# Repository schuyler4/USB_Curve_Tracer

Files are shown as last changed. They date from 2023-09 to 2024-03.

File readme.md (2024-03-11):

<h2> USB Curve Tracer </h2>
This is my attempt at making a curve tracer.  
Instead of implementing a display, data is piped to an external computer where it is plotted using Python. It is also controlled using a command line interface on the external computer. 

Device Picture

<h3> Revision 3 Specs </h3>
<ul>
<li>12V External Power Supply</li>
<li>Maximum Positive Sweep Voltage: 4V</li>
<li>Minimum Negative Sweep Voltage: -3.9V</li>
<li>Full Sweep Time: 15.4s</li>
</ul>

<h3> Limitations </h3>
<ul>
<li>The curve tracer does not use sinusoidal waveforms for measurement; measuring reactive components 
(Capacitors and Inductors) probably will not work. </li>
<li>The curve tracer cannot be driven, so it cannot measure voltage sources.</li>
<li>The curve tracer does not include Kelvin connection functionality, so test lead resistance and 
contact resistance will be included in the measurement. </li>
<li> The curve tracer does not include any programmable gain stages. For this reason, you only get full
current/voltage measurement when using the full current/voltage range.</li>
</ul> 

<h3> Examples </h3>
<p>Below is an example 1N4148 diode sweep and a 2N3904 BJT sweep. Short of curve tracing with a different system and doing a comparison, there is not really a good way to verify if these are correct. However, the general shape of the curves does look right. There is clearly some offset error for the red trace of the 2N3904 sweep. </p>

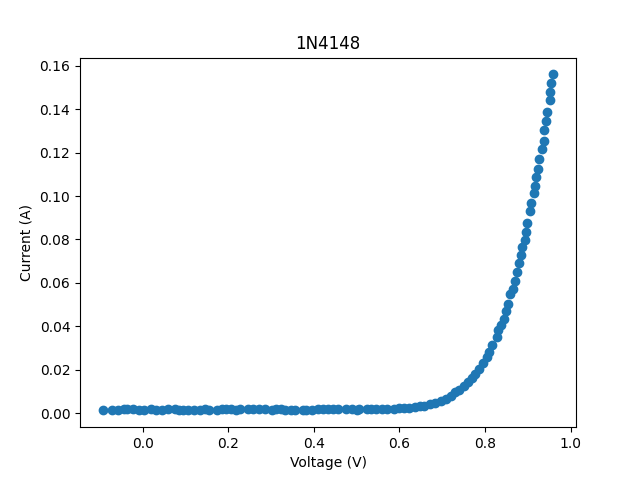
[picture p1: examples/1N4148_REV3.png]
1N4148 Diode

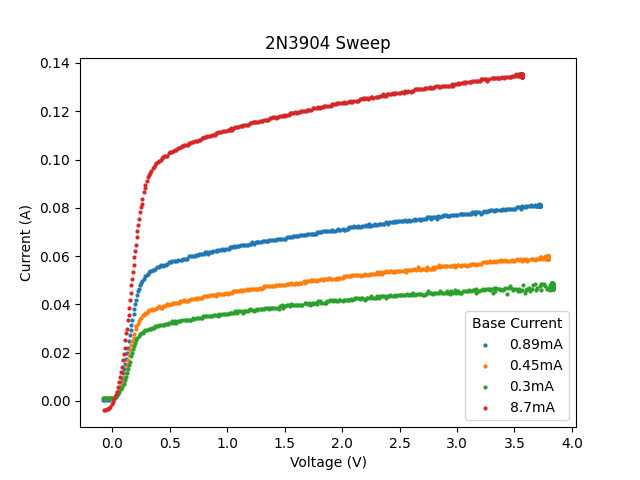
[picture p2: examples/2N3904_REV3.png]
2N3904 BJT


<h3> Schematic </h3>

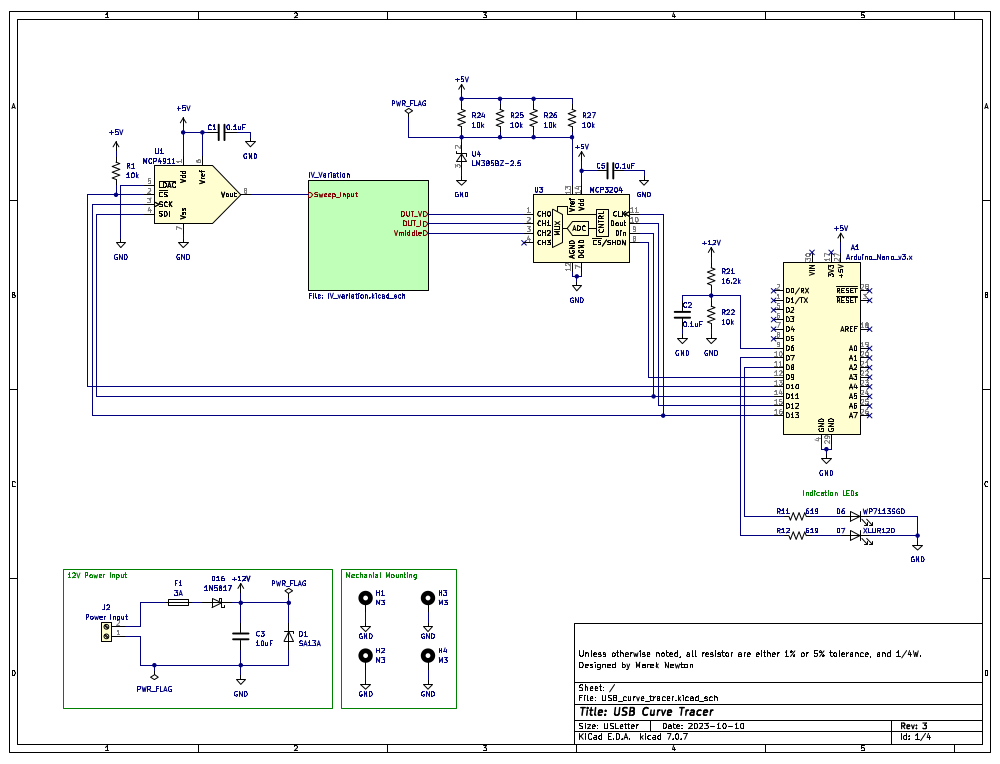
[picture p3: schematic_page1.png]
Schematic Page 1

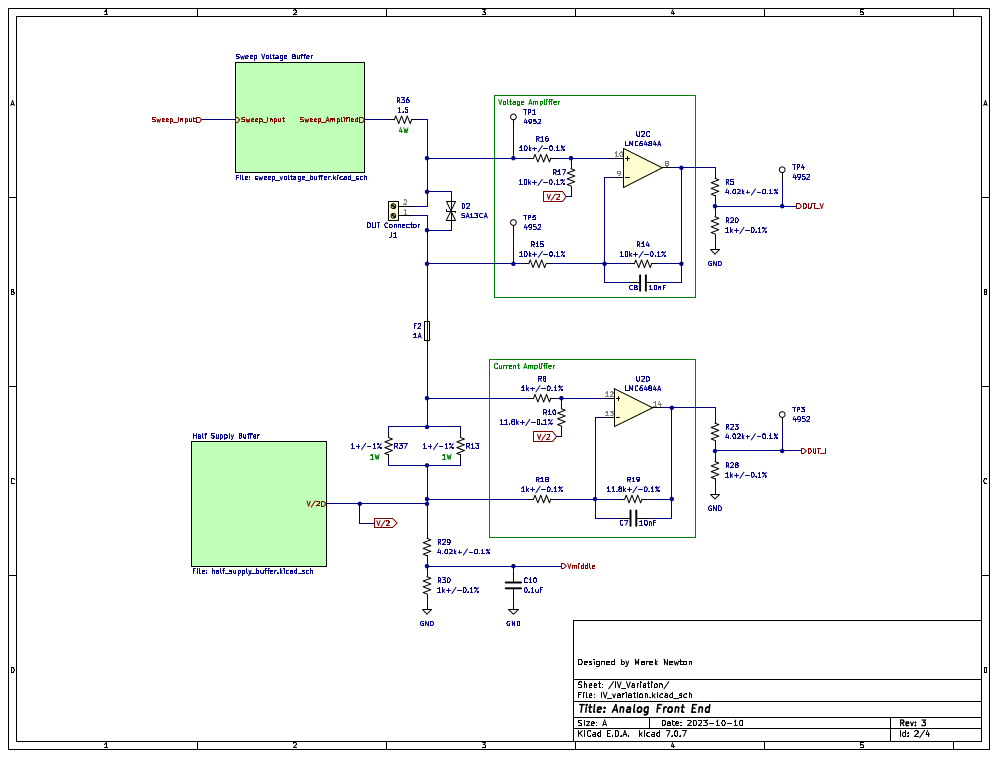
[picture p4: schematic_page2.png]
Schematic Page 2

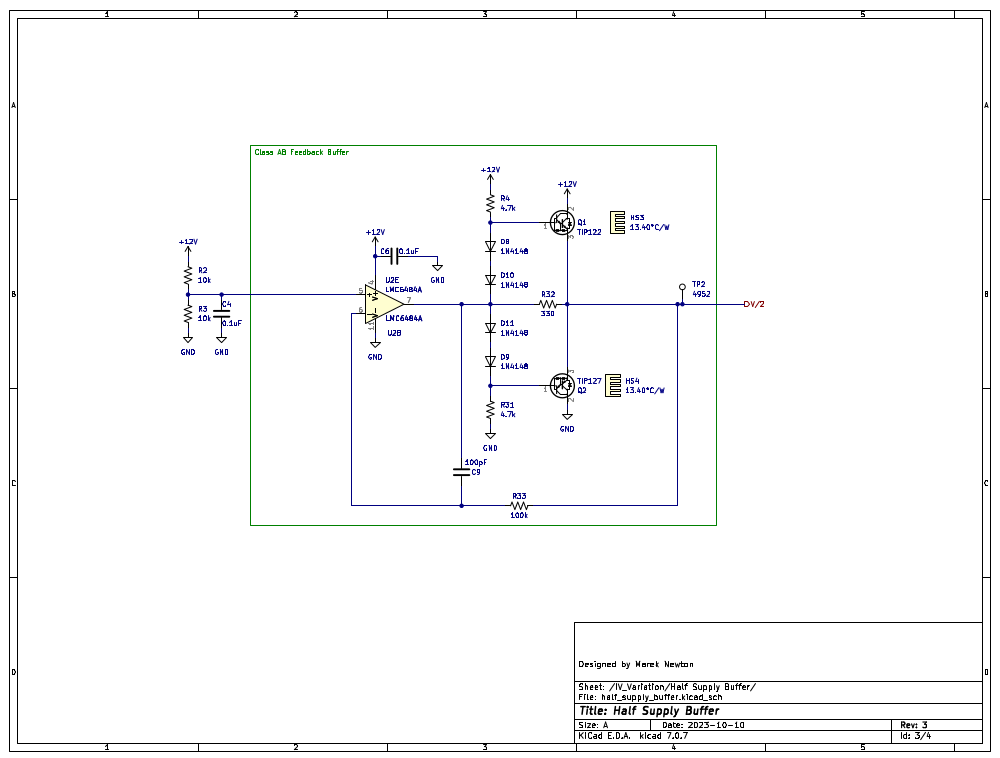
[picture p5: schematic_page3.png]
Schematic Page 3

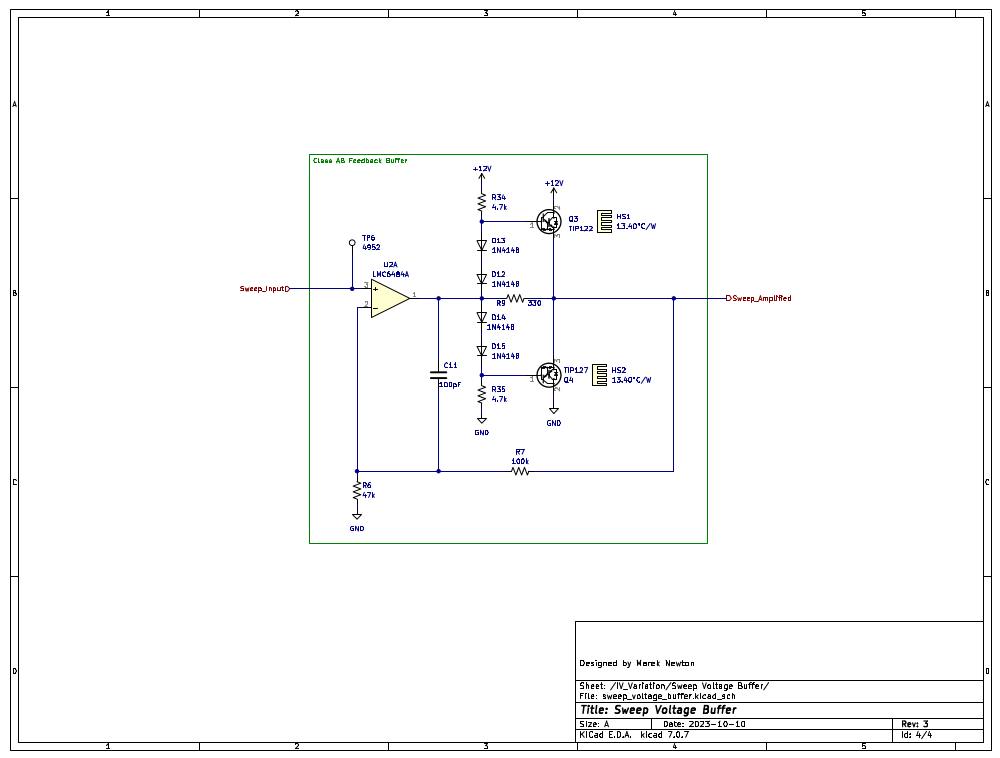
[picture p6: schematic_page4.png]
Schematic Page 4


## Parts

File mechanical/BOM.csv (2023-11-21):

Item | Qty | Value | Distributor | Distributor Part # | Part # | Unit Price | Price
1 | 1 | Enclosure | DIGIKEY | HM616-ND | 1411QU | 16.34 | 16.34
2 | 2 | Red Banana Jack | DIGIKEY | J151-ND | 108-0902-001 | 1.17 | 2.34
3 | 3 | Black Banana Jack | DIGIKEY | J152-ND | 108-0903-001 | 1.26 | 3.78
4 | 4 | Feet | DIGIKEY | SJ-5023-BLACK-ND | SJ-5023-BLACK | 0.29 | 1.16
total: |  |  |  |  |  |  | 23.62
"Assorted M3 screws | M3 nuts | M3 washers | wire | and heatshink are also needed. Standoffs can be 3D printed with the given files.
"

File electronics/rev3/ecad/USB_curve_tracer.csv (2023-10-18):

Source: | C:\Users\marek\Documents\projects\USB_curve_tracer\electronics\rev3\ecad\USB_curve_tracer.kicad_sch
Date: | 10/7/2023 10:38:38 PM
Tool: | Eeschema 7.0.7
Generator: | C:\Program Files\KiCad\6.0\bin\scripting\plugins/bom_csv_grouped_by_value.py
Component Count: | 87
Individual Components:
Item | Qty | Reference(s) | Value | LibPart | Footprint | Datasheet | Distributor Part # | Part # | Sim.Device | Sim.Pins | Unit Price
 |  | A1 | Arduino_Nano_v3.x | MCU_Module:Arduino_Nano_v3.x | Module:Arduino_Nano | http://www.mouser.com/pdfdocs/Gravitech_Arduino_Nano3_0.pdf | 1050-ABX00033-ND | ABX00033 |  |  | 14.91
 |  | C1 | 0.1uF | Device:C | Capacitor_THT:C_Disc_D6.0mm_W2.5mm_P5.00mm | ~ | BC2665CT-ND | K104K10X7RF5UH5 |  |  | 0.23
 |  | C2 | 0.1uF | Device:C | Capacitor_THT:C_Disc_D6.0mm_W2.5mm_P5.00mm | ~ | BC2665CT-ND | K104K10X7RF5UH5 |  |  | 0.23
 |  | C3 | 10uF | Device:C | Capacitor_THT:C_Disc_D6.0mm_W2.5mm_P5.00mm | ~ | 445-173437-1-ND | FG26X7R1E106KRT06 |  |  | 0.65
 |  | C4 | 0.1uF | Device:C | Capacitor_THT:C_Disc_D6.0mm_W2.5mm_P5.00mm | ~ | BC2665CT-ND | K104K10X7RF5UH5 |  |  | 0.23
 |  | C5 | 0.1uF | Device:C | Capacitor_THT:C_Disc_D6.0mm_W2.5mm_P5.00mm | ~ | BC2665CT-ND | K104K10X7RF5UH5 |  |  | 0.23
 |  | C6 | 0.1uF | Device:C | Capacitor_THT:C_Disc_D6.0mm_W2.5mm_P5.00mm | ~ | BC2665CT-ND | K104K10X7RF5UH5 |  |  | 0.23
 |  | C7 | 10nF | Device:C | Capacitor_THT:C_Disc_D6.0mm_W2.5mm_P5.00mm | ~ | BC2662CT-ND | K103K10X7RF5UH5 |  |  | 0.22
 |  | C8 | 10nF | Device:C | Capacitor_THT:C_Disc_D6.0mm_W2.5mm_P5.00mm | ~ | BC2662CT-ND | K103K10X7RF5UH5 |  |  | 0.22
 |  | C9 | 100pF | Device:C | Capacitor_THT:C_Disc_D6.0mm_W2.5mm_P5.00mm | ~ | 56-K101J10C0GF5UH5CT-ND | K101J10C0GF5UH5 |  |  | 0.23
 |  | C10 | 0.1uF | Device:C | Capacitor_THT:C_Disc_D6.0mm_W2.5mm_P5.00mm | ~ | BC2665CT-ND | K104K10X7RF5UH5 |  |  | 0.23
 |  | C11 | 100pF | Device:C | Capacitor_THT:C_Disc_D6.0mm_W2.5mm_P5.00mm | ~ | 56-K101J10C0GF5UH5CT-ND | K101J10C0GF5UH5 |  |  | 0.23
 |  | D1 | SA13A | Device:D_Zener | Diode_THT:D_DO-15_P10.16mm_Horizontal | ~ | SA13A-E3/54GICT-ND | SA13A-E3/54 |  |  | 0.46
 |  | D2 | SA13CA | Device:D_TVS | Diode_THT:D_DO-15_P10.16mm_Horizontal | ~ | SA13CACT-ND | SA13CA |  |  | 0.49
 |  | D3 | BZX79-C2V4 | Device:D_Zener | Diode_THT:D_DO-35_SOD27_P7.62mm_Horizontal | ~ | 1727-2115-1-ND | BZX79-C2V4,113 |  |  | 0.16
 |  | D4 | BZX79-C2V4 | Device:D_Zener | Diode_THT:D_DO-35_SOD27_P7.62mm_Horizontal | ~ | 1727-2115-1-ND | BZX79-C2V4,113 |  |  | 0.16
 |  | D5 | BZX79-C2V4 | Device:D_Zener | Diode_THT:D_DO-35_SOD27_P7.62mm_Horizontal | ~ | 1727-2115-1-ND | BZX79-C2V4,113 |  |  | 0.16
 |  | D6 | WP7113SGD | Device:LED | LED_THT:LED_D5.0mm | ~ | 754-1735-ND | WP7113SGD |  |  | 0.34
 |  | D7 | WP7113ID | Device:LED | LED_THT:LED_D5.0mm | ~ | 754-1264-ND | WP7113ID |  |  | 0.1
 |  | D8 | 1N4148 | Diode:1N4148 | Diode_THT:D_DO-35_SOD27_P7.62mm_Horizontal | https://assets.nexperia.com/documents/data-sheet/1N4148_1N4448.pdf | 1N4148FS-ND | 1N4148 | D | 1=K 2=A | 0.1
 |  | D9 | 1N4148 | Diode:1N4148 | Diode_THT:D_DO-35_SOD27_P7.62mm_Horizontal | https://assets.nexperia.com/documents/data-sheet/1N4148_1N4448.pdf | 1N4148FS-ND | 1N4148 | D | 1=K 2=A | 0.1
 |  | D10 | 1N4148 | Diode:1N4148 | Diode_THT:D_DO-35_SOD27_P7.62mm_Horizontal | https://assets.nexperia.com/documents/data-sheet/1N4148_1N4448.pdf | 1N4148FS-ND | 1N4148 | D | 1=K 2=A | 0.1
 |  | D11 | 1N4148 | Diode:1N4148 | Diode_THT:D_DO-35_SOD27_P7.62mm_Horizontal | https://assets.nexperia.com/documents/data-sheet/1N4148_1N4448.pdf | 1N4148FS-ND | 1N4148 | D | 1=K 2=A | 0.1
 |  | D12 | 1N4148 | Diode:1N4148 | Diode_THT:D_DO-35_SOD27_P7.62mm_Horizontal | https://assets.nexperia.com/documents/data-sheet/1N4148_1N4448.pdf | 1N4148FS-ND | 1N4148 | D | 1=K 2=A | 0.1
 |  | D13 | 1N4148 | Diode:1N4148 | Diode_THT:D_DO-35_SOD27_P7.62mm_Horizontal | https://assets.nexperia.com/documents/data-sheet/1N4148_1N4448.pdf | 1N4148FS-ND | 1N4148 | D | 1=K 2=A | 0.1
 |  | D14 | 1N4148 | Diode:1N4148 | Diode_THT:D_DO-35_SOD27_P7.62mm_Horizontal | https://assets.nexperia.com/documents/data-sheet/1N4148_1N4448.pdf | 1N4148FS-ND | 1N4148 | D | 1=K 2=A | 0.1
 |  | D15 | 1N4148 | Diode:1N4148 | Diode_THT:D_DO-35_SOD27_P7.62mm_Horizontal | https://assets.nexperia.com/documents/data-sheet/1N4148_1N4448.pdf | 1N4148FS-ND | 1N4148 | D | 1=K 2=A | 0.1
 |  | D16 | 1N5817 | Diode:1N5817 | Diode_THT:D_DO-41_SOD81_P10.16mm_Horizontal | http://www.vishay.com/docs/88525/1n5817.pdf | 497-4547-1-ND | 1N5817 |  |  | 0.44
 |  | F1 | 3A | Device:Fuse | Fuse:Fuse_1206_3216Metric_Pad1.42x1.75mm_HandSolder | ~ | 507-1896-1-ND | 0685T3000-01 |  |  | 0.32
 |  | F2 | 1A | Device:Fuse | Fuse:Fuse_1206_3216Metric_Pad1.42x1.75mm_HandSolder | ~ | 507-1893-1-ND | 0685T1500-01 |  |  | 0.32
 |  | HS1 | 13.40°C/W | Mechanical:Heatsink | Library:HSINK_531002B02500G | ~ | HS351-ND | 531002B02500G |  |  | 1.55
 |  | HS2 | 13.40°C/W | Mechanical:Heatsink | Library:HSINK_531002B02500G | ~ | HS351-ND | 531002B02500G |  |  | 1.55
 |  | HS3 | 13.40°C/W | Mechanical:Heatsink | Library:HSINK_531002B02500G | ~ | HS351-ND | 531002B02500G |  |  | 1.55
 |  | HS4 | 13.40°C/W | Mechanical:Heatsink | Library:HSINK_531002B02500G | ~ | HS351-ND | 531002B02500G |  |  | 1.55
 |  | J1 | DUT Connector | Connector:Screw_Terminal_01x02 | TerminalBlock_Phoenix:TerminalBlock_Phoenix_MKDS-1,5-2-5.08_1x02_P5.08mm_Horizontal | ~ | 102-6179-ND | TB004-508-02BE |  |  | 0.71
 |  | J2 | Power Input | Connector:Screw_Terminal_01x02 | TerminalBlock_Phoenix:TerminalBlock_Phoenix_MKDS-1,5-2-5.08_1x02_P5.08mm_Horizontal | ~ | 102-6179-ND | TB004-508-02BE |  |  | 0.71
 |  | Q1 | TIP122 | Transistor_BJT:TIP122 | Package_TO_SOT_THT:TO-220-3_Vertical | https://www.onsemi.com/pub/Collateral/TIP120-D.PDF | TIP122GOS-ND | TIP122G |  |  | 0.79
 |  | Q2 | TIP127 | Transistor_BJT:TIP127 | Package_TO_SOT_THT:TO-220-3_Vertical | https://www.onsemi.com/pub/Collateral/TIP120-D.PDF | TIP127GOS-ND | TIP127G |  |  | 1.37
 |  | Q3 | TIP122 | Transistor_BJT:TIP122 | Package_TO_SOT_THT:TO-220-3_Vertical | https://www.onsemi.com/pub/Collateral/TIP120-D.PDF | TIP122GOS-ND | TIP122G |  |  | 0.79
 |  | Q4 | TIP127 | Transistor_BJT:TIP127 | Package_TO_SOT_THT:TO-220-3_Vertical | https://www.onsemi.com/pub/Collateral/TIP120-D.PDF | TIP127GOS-ND | TIP127G |  |  | 1.37
 |  | R1 | 10k | Device:R_US | Resistor_THT:R_Axial_DIN0207_L6.3mm_D2.5mm_P7.62mm_Horizontal | ~ | CF14JT10K0CT-ND | CF14JT10K0 |  |  | 0.1
 |  | R2 | 10k | Device:R_US | Resistor_THT:R_Axial_DIN0207_L6.3mm_D2.5mm_P7.62mm_Horizontal | ~ | CF14JT10K0CT-ND | CF14JT10K0 |  |  | 0.1
 |  | R3 | 10k | Device:R_US | Resistor_THT:R_Axial_DIN0207_L6.3mm_D2.5mm_P7.62mm_Horizontal | ~ | CF14JT10K0CT-ND | CF14JT10K0 |  |  | 0.1
 |  | R4 | 4.7k | Device:R_US | Resistor_THT:R_Axial_DIN0207_L6.3mm_D2.5mm_P7.62mm_Horizontal | ~ | CF14JT4K70CT-ND | CF14JT4K70 |  |  | 0.1
 |  | R5 | 3.83k+/-0.1% | Device:R_US | Resistor_THT:R_Axial_DIN0207_L6.3mm_D2.5mm_P7.62mm_Horizontal | ~ | 1712-YR1B3K83CCCT-ND | YR1B3K83CC |  |  | 0.63
 |  | R6 | 10k | Device:R_US | Resistor_THT:R_Axial_DIN0207_L6.3mm_D2.5mm_P7.62mm_Horizontal | ~ | CF14JT10K0CT-ND | CF14JT10K0 |  |  | 0.1
 |  | R7 | 10k | Device:R_US | Resistor_THT:R_Axial_DIN0207_L6.3mm_D2.5mm_P7.62mm_Horizontal | ~ | CF14JT10K0CT-ND | CF14JT10K0 |  |  | 0.1
 |  | R8 | 1k+/-0.1% | Device:R_US | Resistor_THT:R_Axial_DIN0207_L6.3mm_D2.5mm_P7.62mm_Horizontal | ~ | A105942CT-ND | YR1B1K0CC |  |  | 0.63
 |  | R9 | 1k | Device:R_US | Resistor_THT:R_Axial_DIN0207_L6.3mm_D2.5mm_P7.62mm_Horizontal | ~ | 13-MFR-25FRF52-1KCT-ND | MFR-25FRF52-1K |  |  | 0.1
 |  | R10 | 11.8k+/-0.1% | Device:R_US | Resistor_THT:R_Axial_DIN0207_L6.3mm_D2.5mm_P7.62mm_Horizontal | ~ | 1712-YR1B11K8CCCT-ND | YR1B11K8CC |  |  | 0.63
 |  | R11 | 619 | Device:R_US | Resistor_THT:R_Axial_DIN0207_L6.3mm_D2.5mm_P7.62mm_Horizontal | ~ | 619XBK-ND | MFR-25FBF52-619R |  |  | 0.1
 |  | R12 | 619 | Device:R_US | Resistor_THT:R_Axial_DIN0207_L6.3mm_D2.5mm_P7.62mm_Horizontal | ~ | 619XBK-ND | MFR-25FBF52-619R |  |  | 0.1
 |  | R13 | 1+/-1% | Device:R_US | Resistor_SMD:R_2512_6332Metric_Pad1.40x3.35mm_HandSolder | ~ | RMCF2512FT1R00CT-ND | RMCF2512FT1R00 |  |  | 0.27
 |  | R14 | 10k+/-0.1% | Device:R_US | Resistor_THT:R_Axial_DIN0207_L6.3mm_D2.5mm_P7.62mm_Horizontal | ~ | A105970CT-ND | YR1B10KCC |  |  | 0.63
 |  | R15 | 10k+/-0.1% | Device:R_US | Resistor_THT:R_Axial_DIN0207_L6.3mm_D2.5mm_P7.62mm_Horizontal | ~ | A105970CT-ND | YR1B10KCC |  |  | 0.63
 |  | R16 | 10k+/-0.1% | Device:R_US | Resistor_THT:R_Axial_DIN0207_L6.3mm_D2.5mm_P7.62mm_Horizontal | ~ | A105970CT-ND | YR1B10KCC |  |  | 0.63
 |  | R17 | 10k+/-0.1% | Device:R_US | Resistor_THT:R_Axial_DIN0207_L6.3mm_D2.5mm_P7.62mm_Horizontal | ~ | A105970CT-ND | YR1B10KCC |  |  | 0.63
 |  | R18 | 1k+/-0.1% | Device:R_US | Resistor_THT:R_Axial_DIN0207_L6.3mm_D2.5mm_P7.62mm_Horizontal | ~ | A105942CT-ND | YR1B1K0CC |  |  | 0.63
 |  | R19 | 11.8k+/-0.1% | Device:R_US | Resistor_THT:R_Axial_DIN0207_L6.3mm_D2.5mm_P7.62mm_Horizontal | ~ | 1712-YR1B11K8CCCT-ND | YR1B11K8CC |  |  | 0.63
 |  | R20 | 1k+/-0.1% | Device:R_US | Resistor_THT:R_Axial_DIN0207_L6.3mm_D2.5mm_P7.62mm_Horizontal | ~ | A105942CT-ND | YR1B1K0CC |  |  | 0.63
 |  | R21 | 14k | Device:R_US | Resistor_THT:R_Axial_DIN0207_L6.3mm_D2.5mm_P7.62mm_Horizontal | ~ | 14.0KXBK-ND | MFR-25FBF52-14K |  |  | 0.1
 |  | R22 | 10k | Device:R_US | Resistor_THT:R_Axial_DIN0207_L6.3mm_D2.5mm_P7.62mm_Horizontal | ~ | CF14JT10K0CT-ND | CF14JT10K0 |  |  | 0.1
 |  | R23 | 3.83k+/-0.1% | Device:R_US | Resistor_THT:R_Axial_DIN0207_L6.3mm_D2.5mm_P7.62mm_Horizontal | ~ | 1712-YR1B3K83CCCT-ND | YR1B3K83CC |  |  | 0.63
 |  | R24 | 10k | Device:R_US | Resistor_THT:R_Axial_DIN0207_L6.3mm_D2.5mm_P7.62mm_Horizontal | ~ | CF14JT10K0CT-ND | CF14JT10K0 |  |  | 0.1
 |  | R25 | 10k | Device:R_US | Resistor_THT:R_Axial_DIN0207_L6.3mm_D2.5mm_P7.62mm_Horizontal | ~ | CF14JT10K0CT-ND | CF14JT10K0 |  |  | 0.1
 |  | R26 | 10k | Device:R_US | Resistor_THT:R_Axial_DIN0207_L6.3mm_D2.5mm_P7.62mm_Horizontal | ~ | CF14JT10K0CT-ND | CF14JT10K0 |  |  | 0.1
 |  | R27 | 10k | Device:R_US | Resistor_THT:R_Axial_DIN0207_L6.3mm_D2.5mm_P7.62mm_Horizontal | ~ | CF14JT10K0CT-ND | CF14JT10K0 |  |  | 0.1
 |  | R28 | 1k+/-0.1% | Device:R_US | Resistor_THT:R_Axial_DIN0207_L6.3mm_D2.5mm_P7.62mm_Horizontal | ~ | A105942CT-ND | YR1B1K0CC |  |  | 0.63
 |  | R29 | 3.83k+/-0.1% | Device:R_US | Resistor_THT:R_Axial_DIN0207_L6.3mm_D2.5mm_P7.62mm_Horizontal | ~ | 1712-YR1B3K83CCCT-ND | YR1B3K83CC |  |  | 0.63
 |  | R30 | 1k | Device:R_US | Resistor_THT:R_Axial_DIN0207_L6.3mm_D2.5mm_P7.62mm_Horizontal | ~ | 13-MFR-25FRF52-1KCT-ND | MFR-25FRF52-1K |  |  | 0.1
 |  | R31 | 4.7k | Device:R_US | Resistor_THT:R_Axial_DIN0207_L6.3mm_D2.5mm_P7.62mm_Horizontal | ~ | CF14JT4K70CT-ND | CF14JT4K70 |  |  | 0.1
 |  | R32 | 1k | Device:R_US | Resistor_THT:R_Axial_DIN0207_L6.3mm_D2.5mm_P7.62mm_Horizontal | ~ | 13-MFR-25FRF52-1KCT-ND | MFR-25FRF52-1K |  |  | 0.1
 |  | R33 | 10k | Device:R_US | Resistor_THT:R_Axial_DIN0207_L6.3mm_D2.5mm_P7.62mm_Horizontal | ~ | CF14JT10K0CT-ND | CF14JT10K0 |  |  | 0.1
 |  | R34 | 4.7k | Device:R_US | Resistor_THT:R_Axial_DIN0207_L6.3mm_D2.5mm_P7.62mm_Horizontal | ~ | CF14JT4K70CT-ND | CF14JT4K70 |  |  | 0.1
 |  | R35 | 4.7k | Device:R_US | Resistor_THT:R_Axial_DIN0207_L6.3mm_D2.5mm_P7.62mm_Horizontal | ~ | CF14JT4K70CT-ND | CF14JT4K70 |  |  | 0.1
 |  | R36 | 1.5 | Device:R_US | Resistor_SMD:R_2512_6332Metric_Pad1.40x3.35mm_HandSolder | ~ | A121179CT-ND | 35221R5JT |  |  | 1.22
 |  | R37 | 1+/-1% | Device:R_US | Resistor_SMD:R_2512_6332Metric_Pad1.40x3.35mm_HandSolder | ~ | RMCF2512FT1R00CT-ND | RMCF2512FT1R00 |  |  | 0.27
 |  | TP1 | 4952 | Connector:TestPoint | TestPoint:TestPoint_THTPad_D2.5mm_Drill1.2mm | ~ | 36-4952-ND | 4952 |  |  | 0.26
 |  | TP2 | 4952 | Connector:TestPoint | TestPoint:TestPoint_THTPad_D2.5mm_Drill1.2mm | ~ | 36-4952-ND | 4952 |  |  | 0.26
 |  | TP3 | 4952 | Connector:TestPoint | TestPoint:TestPoint_THTPad_D2.5mm_Drill1.2mm | ~ | 36-4952-ND | 4952 |  |  | 0.26
 |  | TP4 | 4952 | Connector:TestPoint | TestPoint:TestPoint_THTPad_D2.5mm_Drill1.2mm | ~ | 36-4952-ND | 4952 |  |  | 0.26
 |  | TP5 | 4952 | Connector:TestPoint | TestPoint:TestPoint_THTPad_D2.5mm_Drill1.2mm | ~ | 36-4952-ND | 4952 |  |  | 0.26
 |  | TP6 | 4952 | Connector:TestPoint | TestPoint:TestPoint_THTPad_D2.5mm_Drill1.2mm | ~ | 36-4952-ND | 4952 |  |  | 0.26
 |  | U1 | MCP4911 | Analog_DAC:MCP4911 | Package_DIP:DIP-8_W7.62mm | http://ww1.microchip.com/downloads/en/DeviceDoc/22248a.pdf | MCP4911-E/P-ND | MCP4911-E/P |  |  | 1.97
 |  | U2 | LMC6484A | Amplifier_Operational:LM6144xIx | Package_DIP:DIP-14_W7.62mm | https://www.ti.com/lit/ds/symlink/lm6142.pdf | LMC6484IN/NOPB-ND | LMC6484IN/NOPB |  |  | 2.83
 |  | U3 | MCP3204 | Analog_ADC:MCP3204 | Package_DIP:DIP-14_W7.62mm | http://ww1.microchip.com/downloads/en/DeviceDoc/21298c.pdf | MCP3204-CI/P-ND | MCP3204-CI/P |  |  | 4.52
 |  | U4 | LM385BZ-2.5 | Reference_Voltage:LM385BZ-2.5 | Package_TO_SOT_THT:TO-92_Inline | http://www.onsemi.com/pub_link/Collateral/LM285-D.PDF | LM385BZ-2.5GOS-ND | LM385BZ-2.5G |  |  | 0.78
Collated Components:
Item | Qty | Reference(s) | Value | LibPart | Footprint | Datasheet | Distributor Part # | Part # | Sim.Device | Sim.Pins | Unit Price
1 | 1 | A1 | Arduino_Nano_v3.x | MCU_Module:Arduino_Nano_v3.x | Module:Arduino_Nano | http://www.mouser.com/pdfdocs/Gravitech_Arduino_Nano3_0.pdf | 1050-ABX00033-ND | ABX00033 |  |  | 14.91
2 | 6 | C1, C2, C4, C5, C6, C10 | 0.1uF | Device:C | Capacitor_THT:C_Disc_D6.0mm_W2.5mm_P5.00mm | ~ | BC2665CT-ND | K104K10X7RF5UH5 |  |  | 0.23
3 | 1 | C3 | 10uF | Device:C | Capacitor_THT:C_Disc_D6.0mm_W2.5mm_P5.00mm | ~ | 445-173437-1-ND | FG26X7R1E106KRT06 |  |  | 0.65
4 | 2 | C7, C8 | 10nF | Device:C | Capacitor_THT:C_Disc_D6.0mm_W2.5mm_P5.00mm | ~ | BC2662CT-ND | K103K10X7RF5UH5 |  |  | 0.22
5 | 2 | C9, C11 | 100pF | Device:C | Capacitor_THT:C_Disc_D6.0mm_W2.5mm_P5.00mm | ~ | 56-K101J10C0GF5UH5CT-ND | K101J10C0GF5UH5 |  |  | 0.23
6 | 1 | D1 | SA13A | Device:D_Zener | Diode_THT:D_DO-15_P10.16mm_Horizontal | ~ | SA13A-E3/54GICT-ND | SA13A-E3/54 |  |  | 0.46
7 | 1 | D2 | SA13CA | Device:D_TVS | Diode_THT:D_DO-15_P10.16mm_Horizontal | ~ | SA13CACT-ND | SA13CA |  |  | 0.49
8 | 3 | D3, D4, D5 | BZX79-C2V4 | Device:D_Zener | Diode_THT:D_DO-35_SOD27_P7.62mm_Horizontal | ~ | 1727-2115-1-ND | BZX79-C2V4,113 |  |  | 0.16
9 | 1 | D6 | WP7113SGD | Device:LED | LED_THT:LED_D5.0mm | ~ | 754-1735-ND | WP7113SGD |  |  | 0.34
10 | 1 | D7 | WP7113ID | Device:LED | LED_THT:LED_D5.0mm | ~ | 754-1264-ND | WP7113ID |  |  | 0.1
11 | 8 | D8, D9, D10, D11, D12, D13, D14, D15 | 1N4148 | Diode:1N4148 | Diode_THT:D_DO-35_SOD27_P7.62mm_Horizontal | https://assets.nexperia.com/documents/data-sheet/1N4148_1N4448.pdf | 1N4148FS-ND | 1N4148 | D | 1=K 2=A | 0.1
12 | 1 | D16 | 1N5817 | Diode:1N5817 | Diode_THT:D_DO-41_SOD81_P10.16mm_Horizontal | http://www.vishay.com/docs/88525/1n5817.pdf | 497-4547-1-ND | 1N5817 |  |  | 0.44
13 | 1 | F1 | 3A | Device:Fuse | Fuse:Fuse_1206_3216Metric_Pad1.42x1.75mm_HandSolder | ~ | 507-1896-1-ND | 0685T3000-01 |  |  | 0.32
14 | 1 | F2 | 1A | Device:Fuse | Fuse:Fuse_1206_3216Metric_Pad1.42x1.75mm_HandSolder | ~ | 507-1893-1-ND | 0685T1500-01 |  |  | 0.32
15 | 4 | HS1, HS2, HS3, HS4 | 13.40°C/W | Mechanical:Heatsink | Library:HSINK_531002B02500G | ~ | HS351-ND | 531002B02500G |  |  | 1.55
16 | 1 | J1 | DUT Connector | Connector:Screw_Terminal_01x02 | TerminalBlock_Phoenix:TerminalBlock_Phoenix_MKDS-1,5-2-5.08_1x02_P5.08mm_Horizontal | ~ | 102-6179-ND | TB004-508-02BE |  |  | 0.71
17 | 1 | J2 | Power Input | Connector:Screw_Terminal_01x02 | TerminalBlock_Phoenix:TerminalBlock_Phoenix_MKDS-1,5-2-5.08_1x02_P5.08mm_Horizontal | ~ | 102-6179-ND | TB004-508-02BE |  |  | 0.71
18 | 2 | Q1, Q3 | TIP122 | Transistor_BJT:TIP122 | Package_TO_SOT_THT:TO-220-3_Vertical | https://www.onsemi.com/pub/Collateral/TIP120-D.PDF | TIP122GOS-ND | TIP122G |  |  | 0.79
19 | 2 | Q2, Q4 | TIP127 | Transistor_BJT:TIP127 | Package_TO_SOT_THT:TO-220-3_Vertical | https://www.onsemi.com/pub/Collateral/TIP120-D.PDF | TIP127GOS-ND | TIP127G |  |  | 1.37
20 | 11 | R1, R2, R3, R6, R7, R22, R24, R25, R26, R27, R33 | 10k | Device:R_US | Resistor_THT:R_Axial_DIN0207_L6.3mm_D2.5mm_P7.62mm_Horizontal | ~ | CF14JT10K0CT-ND | CF14JT10K0 |  |  | 0.1
21 | 4 | R4, R31, R34, R35 | 4.7k | Device:R_US | Resistor_THT:R_Axial_DIN0207_L6.3mm_D2.5mm_P7.62mm_Horizontal | ~ | CF14JT4K70CT-ND | CF14JT4K70 |  |  | 0.1
22 | 3 | R5, R23, R29 | 3.83k+/-0.1% | Device:R_US | Resistor_THT:R_Axial_DIN0207_L6.3mm_D2.5mm_P7.62mm_Horizontal | ~ | 1712-YR1B3K83CCCT-ND | YR1B3K83CC |  |  | 0.63
23 | 4 | R8, R18, R20, R28 | 1k+/-0.1% | Device:R_US | Resistor_THT:R_Axial_DIN0207_L6.3mm_D2.5mm_P7.62mm_Horizontal | ~ | A105942CT-ND | YR1B1K0CC |  |  | 0.63
24 | 3 | R9, R30, R32 | 1k | Device:R_US | Resistor_THT:R_Axial_DIN0207_L6.3mm_D2.5mm_P7.62mm_Horizontal | ~ | 13-MFR-25FRF52-1KCT-ND | MFR-25FRF52-1K |  |  | 0.1
25 | 2 | R10, R19 | 11.8k+/-0.1% | Device:R_US | Resistor_THT:R_Axial_DIN0207_L6.3mm_D2.5mm_P7.62mm_Horizontal | ~ | 1712-YR1B11K8CCCT-ND | YR1B11K8CC |  |  | 0.63
26 | 2 | R11, R12 | 619 | Device:R_US | Resistor_THT:R_Axial_DIN0207_L6.3mm_D2.5mm_P7.62mm_Horizontal | ~ | 619XBK-ND | MFR-25FBF52-619R |  |  | 0.1
27 | 2 | R13, R37 | 1+/-1% | Device:R_US | Resistor_SMD:R_2512_6332Metric_Pad1.40x3.35mm_HandSolder | ~ | RMCF2512FT1R00CT-ND | RMCF2512FT1R00 |  |  | 0.27
28 | 4 | R14, R15, R16, R17 | 10k+/-0.1% | Device:R_US | Resistor_THT:R_Axial_DIN0207_L6.3mm_D2.5mm_P7.62mm_Horizontal | ~ | A105970CT-ND | YR1B10KCC |  |  | 0.63
29 | 1 | R21 | 14k | Device:R_US | Resistor_THT:R_Axial_DIN0207_L6.3mm_D2.5mm_P7.62mm_Horizontal | ~ | 14.0KXBK-ND | MFR-25FBF52-14K |  |  | 0.1
30 | 1 | R36 | 1.5 | Device:R_US | Resistor_SMD:R_2512_6332Metric_Pad1.40x3.35mm_HandSolder | ~ | A121179CT-ND | 35221R5JT |  |  | 1.22
31 | 6 | TP1, TP2, TP3, TP4, TP5, TP6 | 4952 | Connector:TestPoint | TestPoint:TestPoint_THTPad_D2.5mm_Drill1.2mm | ~ | 36-4952-ND | 4952 |  |  | 0.26
32 | 1 | U1 | MCP4911 | Analog_DAC:MCP4911 | Package_DIP:DIP-8_W7.62mm | http://ww1.microchip.com/downloads/en/DeviceDoc/22248a.pdf | MCP4911-E/P-ND | MCP4911-E/P |  |  | 1.97
33 | 1 | U2 | LMC6484A | Amplifier_Operational:LM6144xIx | Package_DIP:DIP-14_W7.62mm | https://www.ti.com/lit/ds/symlink/lm6142.pdf | LMC6484IN/NOPB-ND | LMC6484IN/NOPB |  |  | 2.83
34 | 1 | U3 | MCP3204 | Analog_ADC:MCP3204 | Package_DIP:DIP-14_W7.62mm | http://ww1.microchip.com/downloads/en/DeviceDoc/21298c.pdf | MCP3204-CI/P-ND | MCP3204-CI/P |  |  | 4.52
35 | 1 | U4 | LM385BZ-2.5 | Reference_Voltage:LM385BZ-2.5 | Package_TO_SOT_THT:TO-92_Inline | http://www.onsemi.com/pub_link/Collateral/LM285-D.PDF | LM385BZ-2.5GOS-ND | LM385BZ-2.5G |  |  | 0.78

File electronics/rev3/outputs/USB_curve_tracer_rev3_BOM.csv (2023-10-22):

Item | Qty | Reference(s) | Value | Distributor | Distributor Part # | Part # | Unit Price | Price | Carted
1 | 1 | A1 | Arduino_Nano_v3.x | AMAZON | B0713XK923 | EL-CB-005 | 14.91 | 14.91
2 | 6 | C1, C2, C4, C5, C6, C10 | 0.1uF | DIGIKEY | BC2665CT-ND | K104K10X7RF5UH5 | 0.23 | 1.38 | T
3 | 1 | C3 | 10uF | DIGIKEY | 445-173437-1-ND | FG26X7R1E106KRT06 | 0.65 | 0.65 | T
4 | 2 | C7, C8 | 10nF | DIGIKEY | BC2662CT-ND | K103K10X7RF5UH5 | 0.22 | 0.44 | T
5 | 2 | C9, C11 | 100pF | DIGIKEY | 56-K101J10C0GF5UH5CT-ND | K101J10C0GF5UH5 | 0.23 | 0.46 | T
6 | 1 | D1 | SA13A | DIGIKEY | SA13A-E3/54GICT-ND | SA13A-E3/54 | 0.46 | 0.46 | T
7 | 1 | D2 | SA13CA | DIGIKEY | SA13CACT-ND | SA13CA | 0.49 | 0.49 | T
8 | 3 | D3, D4, D5 | BZX79-C2V4 | DIGIKEY | 1727-2115-1-ND | BZX79-C2V4,113 | 0.16 | 0.48 | T
9 | 1 | D6 | WP7113SGD | DIGIKEY | 754-1735-ND | WP7113SGD | 0.34 | 0.34 | T
10 | 1 | D7 | XLUR12D | DIGIKEY | 1497-1031-ND | XLUR12D | 0.28 | 0.28 | T
11 | 8 | D8, D9, D10, D11, D12, D13, D14, D15 | 1N4148 | DIGIKEY | 1N4148FS-ND | 1N4148 | 0.1 | 0.8 | T
12 | 1 | D16 | 1N5817 | DIGIKEY | 497-4547-1-ND | 1N5817 | 0.44 | 0.44 | T
13 | 1 | F1 | 3A | DIGIKEY | 507-1896-1-ND | 0685T3000-01 | 0.32 | 0.32 | T
14 | 1 | F2 | 1A | DIGIKEY | 507-1077-1-ND | C1Q 1 | 0.33 | 0.33 | T
15 | 4 | HS1, HS2, HS3, HS4 | 13.40°C/W | DIGIKEY | HS351-ND | 531002B02500G | 1.55 | 6.2 | T
16 | 1 | J1 | DUT Connector | DIGIKEY | 102-6179-ND | TB004-508-02BE | 0.71 | 0.71 | T
17 | 1 | J2 | Power Input | DIGIKEY | 102-6179-ND | TB004-508-02BE | 0.71 | 0.71 | T
18 | 2 | Q1, Q3 | TIP122 | DIGIKEY | 497-2543-5-ND | TIP122 | 0.79 | 1.58 | T
19 | 2 | Q2, Q4 | TIP127 | DIGIKEY | TIP127GOS-ND | TIP127G | 1.37 | 2.74 | T
20 | 11 | R1, R2, R3, R6, R7, R22, R24, R25, R26, R27, R33 | 10k | DIGIKEY | CF14JT10K0CT-ND | CF14JT10K0 | 0.1 | 1.1 | T
21 | 4 | R4, R31, R34, R35 | 4.7k | DIGIKEY | CF14JT4K70CT-ND | CF14JT4K70 | 0.1 | 0.4 | T
22 | 3 | R5, R23, R29 | 4.02k+/-0.1% | DIGIKEY | 1712-YR1B4K02CT-ND | YR1B4K02 | 0.63 | 1.89 | T
23 | 4 | R8, R18, R20, R28 | 1k+/-0.1% | DIGIKEY | A105942CT-ND | YR1B1K0CC | 0.63 | 2.52 | T
24 | 3 | R9, R30, R32 | 1k | DIGIKEY | 13-MFR-25FRF52-1KCT-ND | MFR-25FRF52-1K | 0.1 | 0.3 | T
25 | 2 | R10, R19 | 11.8k+/-0.1% | DIGIKEY | 1712-YR1B11K8CCCT-ND | YR1B11K8CC | 0.63 | 1.26 | T
26 | 2 | R11, R12 | 619 | DIGIKEY | 619XBK-ND | MFR-25FBF52-619R | 0.1 | 0.2 | T
27 | 2 | R13, R37 | 1+/-1% | DIGIKEY | RMCF2512FT1R00CT-ND | RMCF2512FT1R00 | 0.27 | 0.54 | T
28 | 4 | R14, R15, R16, R17 | 10k+/-0.1% | DIGIKEY | A105970CT-ND | YR1B10KCC | 0.63 | 2.52 | T
29 | 1 | R21 | 16.2k | DIGIKEY | 16.2KXBK-ND | MFR-25FBF52-16K2 | 0.1 | 0.1 | T
30 | 1 | R36 | 1.5 | DIGIKEY | A121179CT-ND | 35221R5JT | 1.22 | 1.22 | T
31 | 6 | TP1, TP2, TP3, TP4, TP5, TP6 | 4952 | DIGIKEY | 36-4952-ND | 4952 | 0.26 | 1.56 | T
32 | 1 | U1 | MCP4911 | DIGIKEY | MCP4911-E/P-ND | MCP4911-E/P | 1.97 | 1.97 | T
33 | 1 | U2 | LMC6484A | DIGIKEY | LMC6484IN/NOPB-ND | LMC6484IN/NOPB | 2.83 | 2.83 | T
34 | 1 | U3 | MCP3204 | DIGIKEY | MCP3204-CI/P-ND | MCP3204-CI/P | 4.52 | 4.52 | T
35 | 1 | U4 | LM385BZ-2.5 | DIGIKEY | LM385BZ-2.5GOS-ND | LM385BZ-2.5G | 0.78 | 0.78 | T
 |  |  |  |  |  |  |  | 57.25

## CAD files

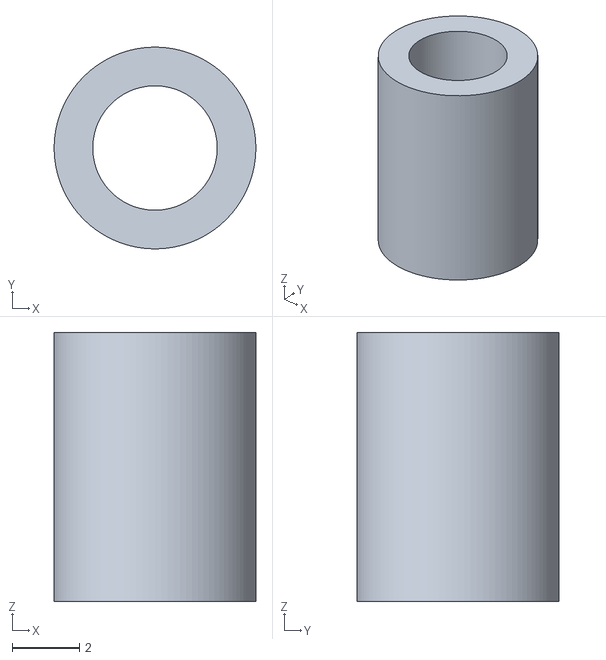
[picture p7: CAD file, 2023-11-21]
mechanical/M3_stand_off.stl
6.00 x 6.00 x 8.00

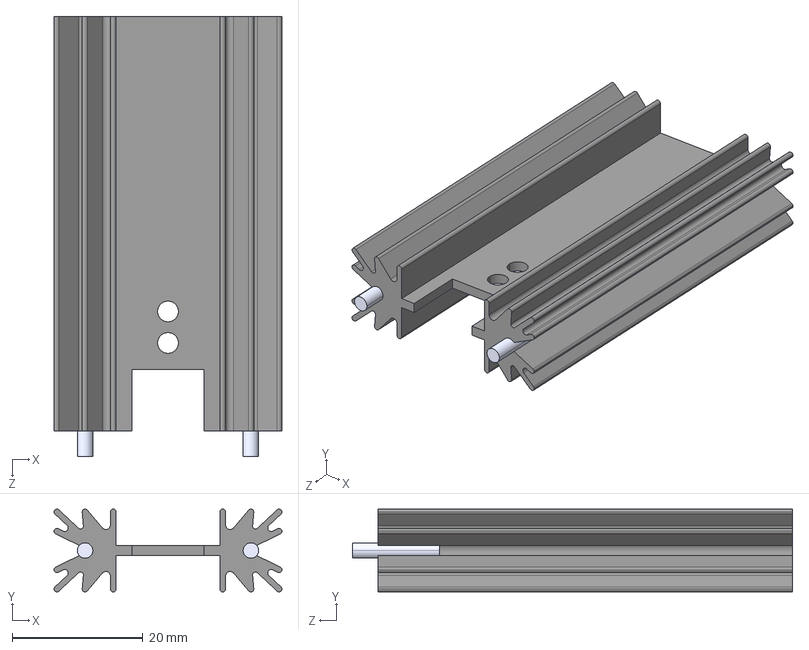
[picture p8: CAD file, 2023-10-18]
electronics/rev3/ecad/mechanical_models/531002B02500G.step
34.9 x 12.7 x 67.5 mm

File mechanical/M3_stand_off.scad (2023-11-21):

// M3 Stand Off
OUTER_DIAMETER = 6;
INNER_DIAMETER = 3.7;
HEIGHT = 8;
OFFSET=2;
RESOLUTION=100;

difference()
{
    cylinder(h=HEIGHT, d=OUTER_DIAMETER, center=true, $fn=RESOLUTION);
    cylinder(h=HEIGHT+OFFSET, d=INNER_DIAMETER, center=true, $fn=RESOLUTION);
}

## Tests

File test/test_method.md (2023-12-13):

<h2> USB Curve Tracer Test Method </h2>
<h3> Sweep Test </h3>
The curve tracer is tested by sweeping a number of different resistor values.
Once all this data is collected, a best fit line for each tested resistor value
is found. The percent error between the theoretical resistor IV curve, and the measured resistor value IV curve is found.

The following resistor values are tested: 470, 330, 220, 33

This test is not automated with the curve tracer in loop. Each resistor is manually measured,
and the data is saved in the test directory. 

<b>acceptance criteria:</b>
The error between the theoretical resistor curve slope, and the measured
resistor curve slope is less than 15%. 
The offset must be less than 0.005 for the measured curve. 
(remember, the curve tracer is only to get a rough idea of the device curve)

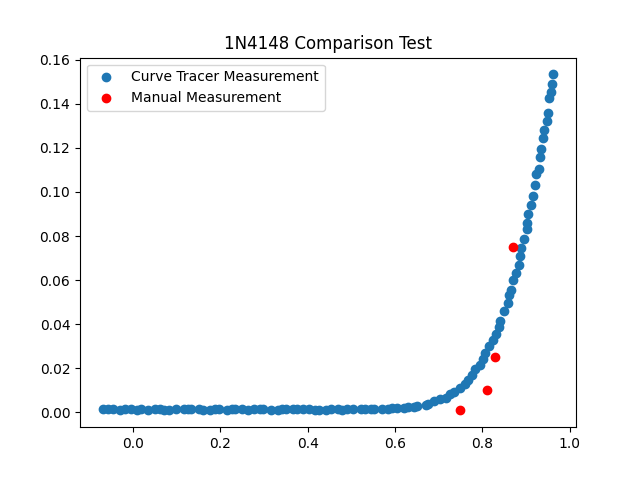
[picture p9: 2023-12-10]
test/rev3_diode_comparison_test/1N4148_comparison.png

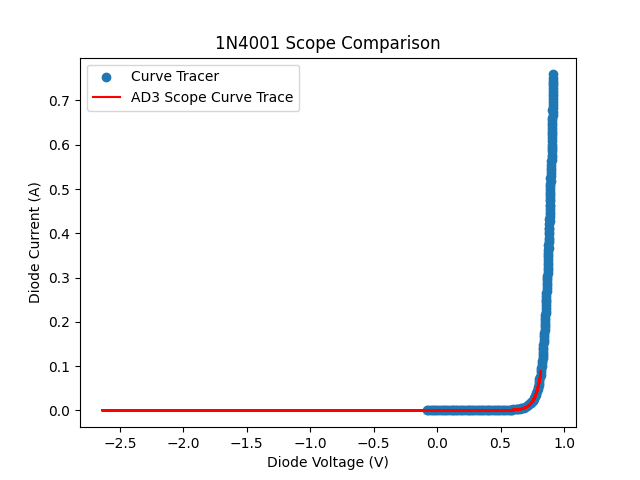
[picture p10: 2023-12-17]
test/rev3_scope_comparison/1N4001_scope_comparison.png

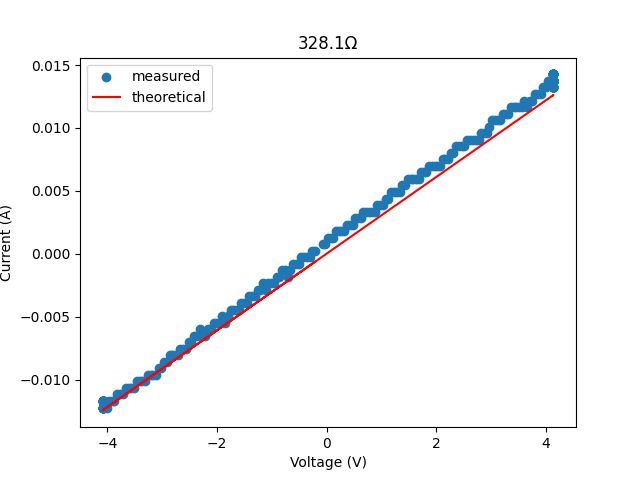
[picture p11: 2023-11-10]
test/rev3_test_LMC6484/resistor_test/test_plot/328.1.png

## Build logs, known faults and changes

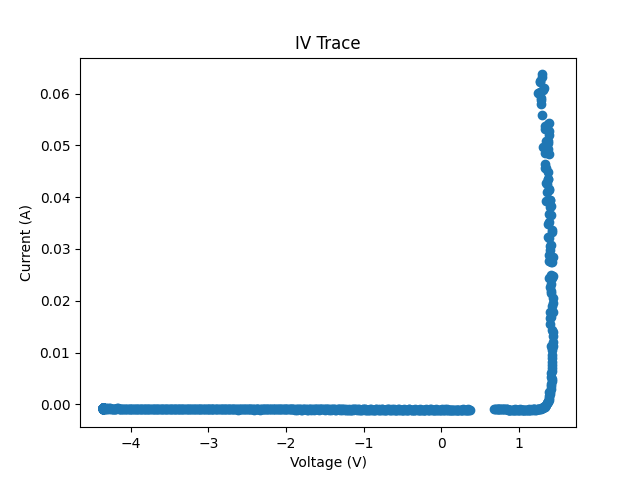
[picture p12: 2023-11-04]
debug/bad_diode_trace.png

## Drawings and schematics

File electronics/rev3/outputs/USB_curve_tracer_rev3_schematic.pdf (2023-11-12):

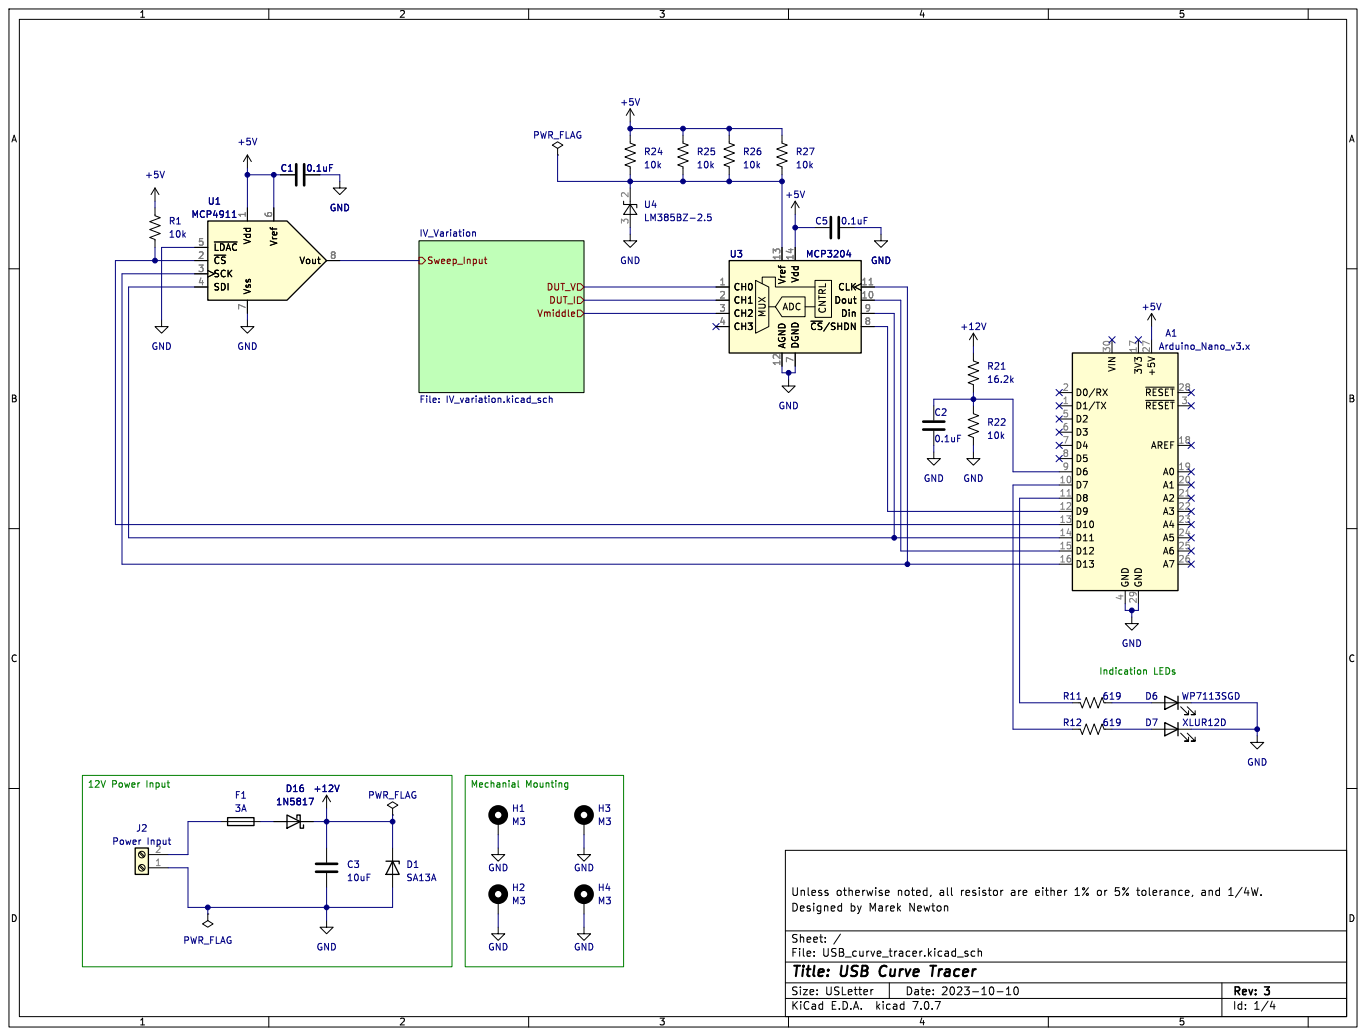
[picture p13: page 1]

1 ~{CS} 2 SCK 3 SDI 4 ~{LDAC} 5 Vref 6 Vss 7 Vout 8 U1 MCP4911 +5V R1

7 ~{CS}/SHDN 8 Din 9 U1 MCP4911 Vdd

1 ~{CS} 2 SCK 3 SDI 4 ~{LDAC} 5 Vref 6 Vss 7 Vout 8GND

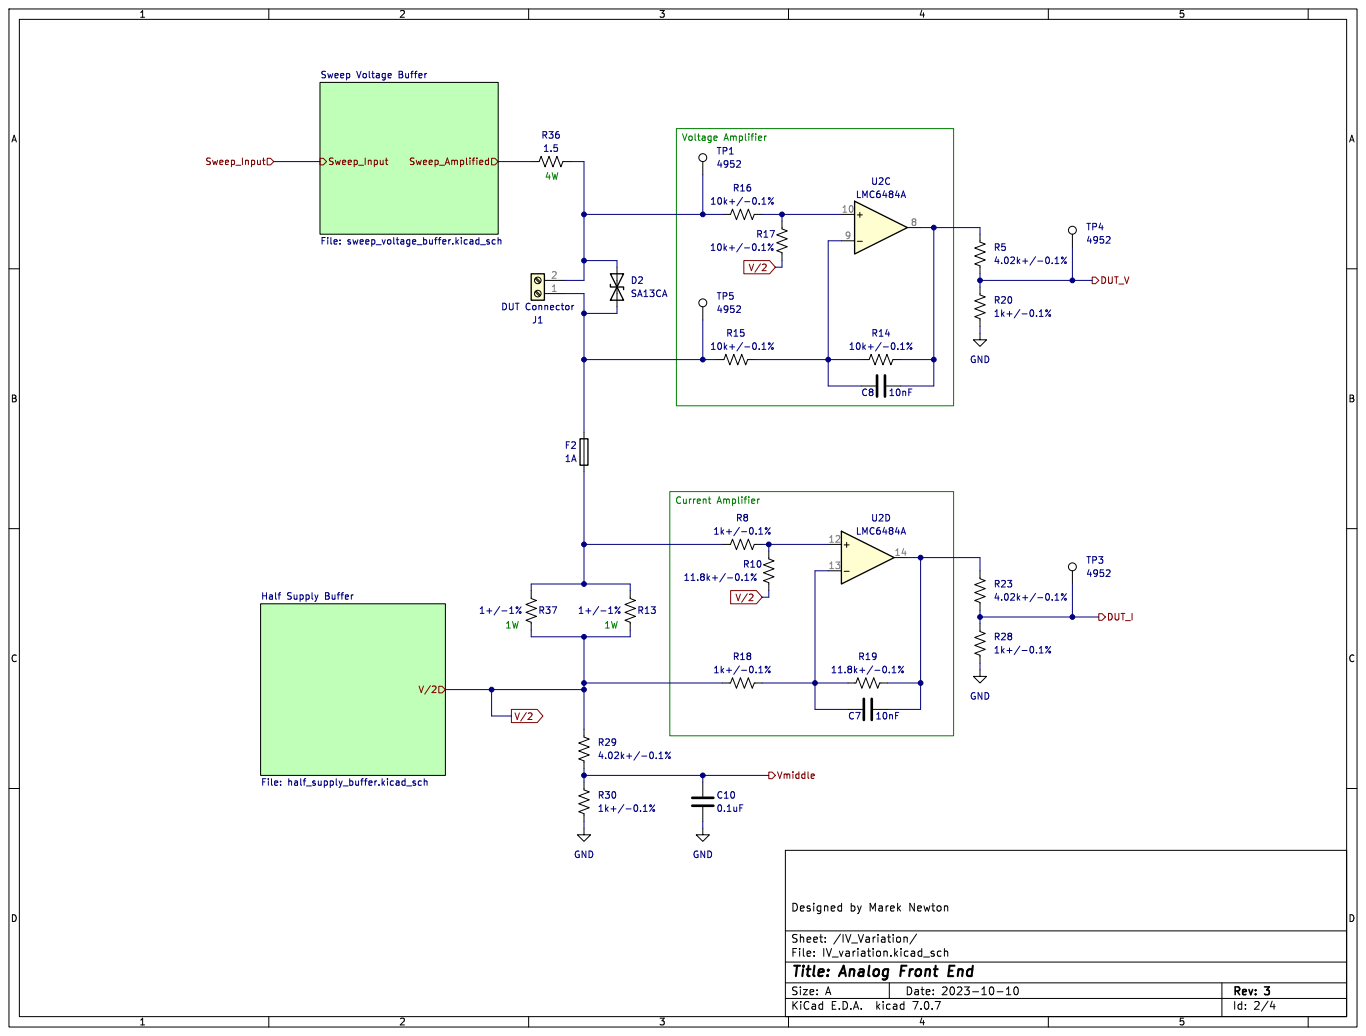
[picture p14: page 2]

Voltage Amplifier Current Amplifier

File: IV_variation.kicad_sch Sheet: /IV_Variation/
Id: 2/4 Title: Analog Front End

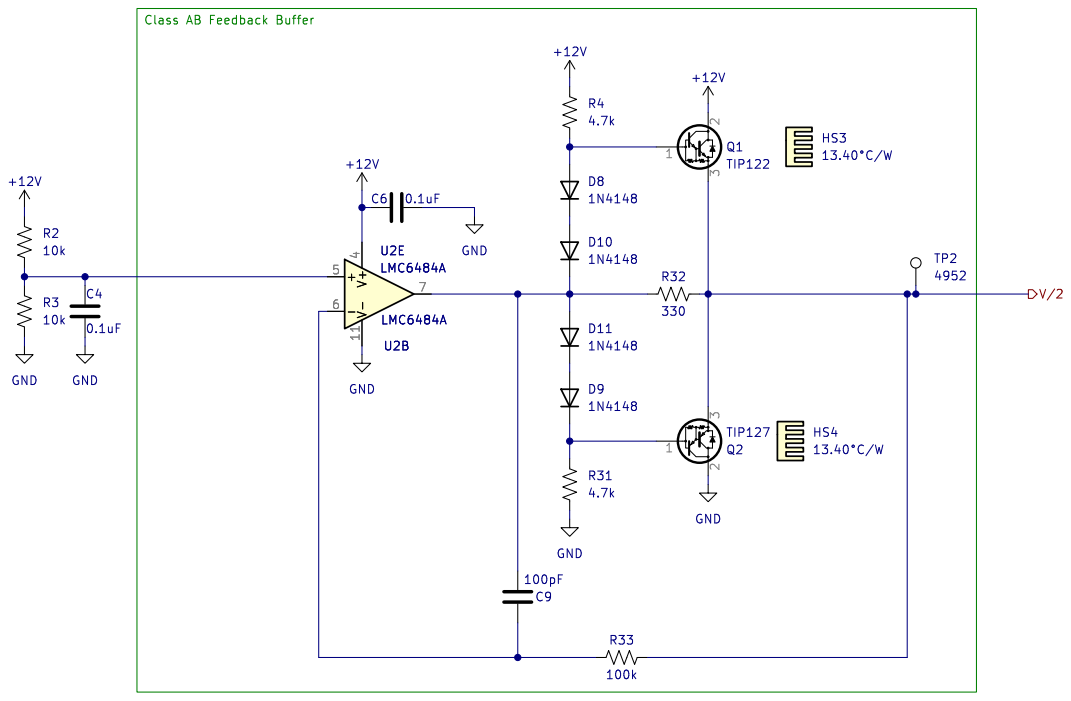
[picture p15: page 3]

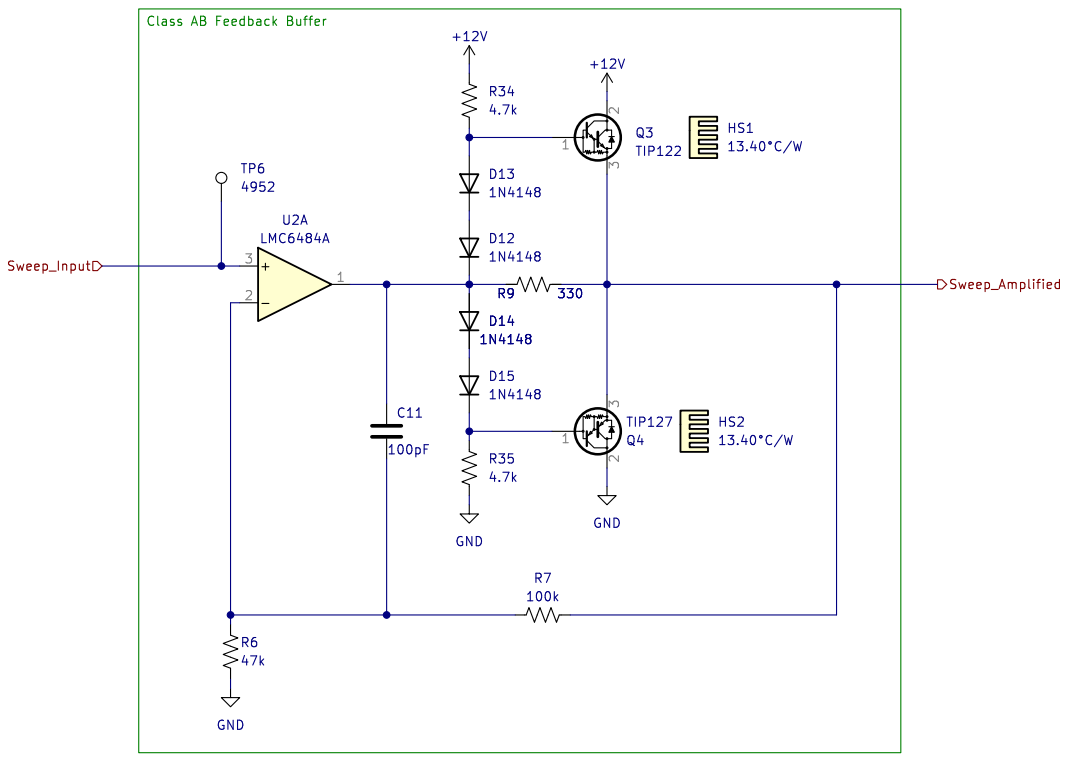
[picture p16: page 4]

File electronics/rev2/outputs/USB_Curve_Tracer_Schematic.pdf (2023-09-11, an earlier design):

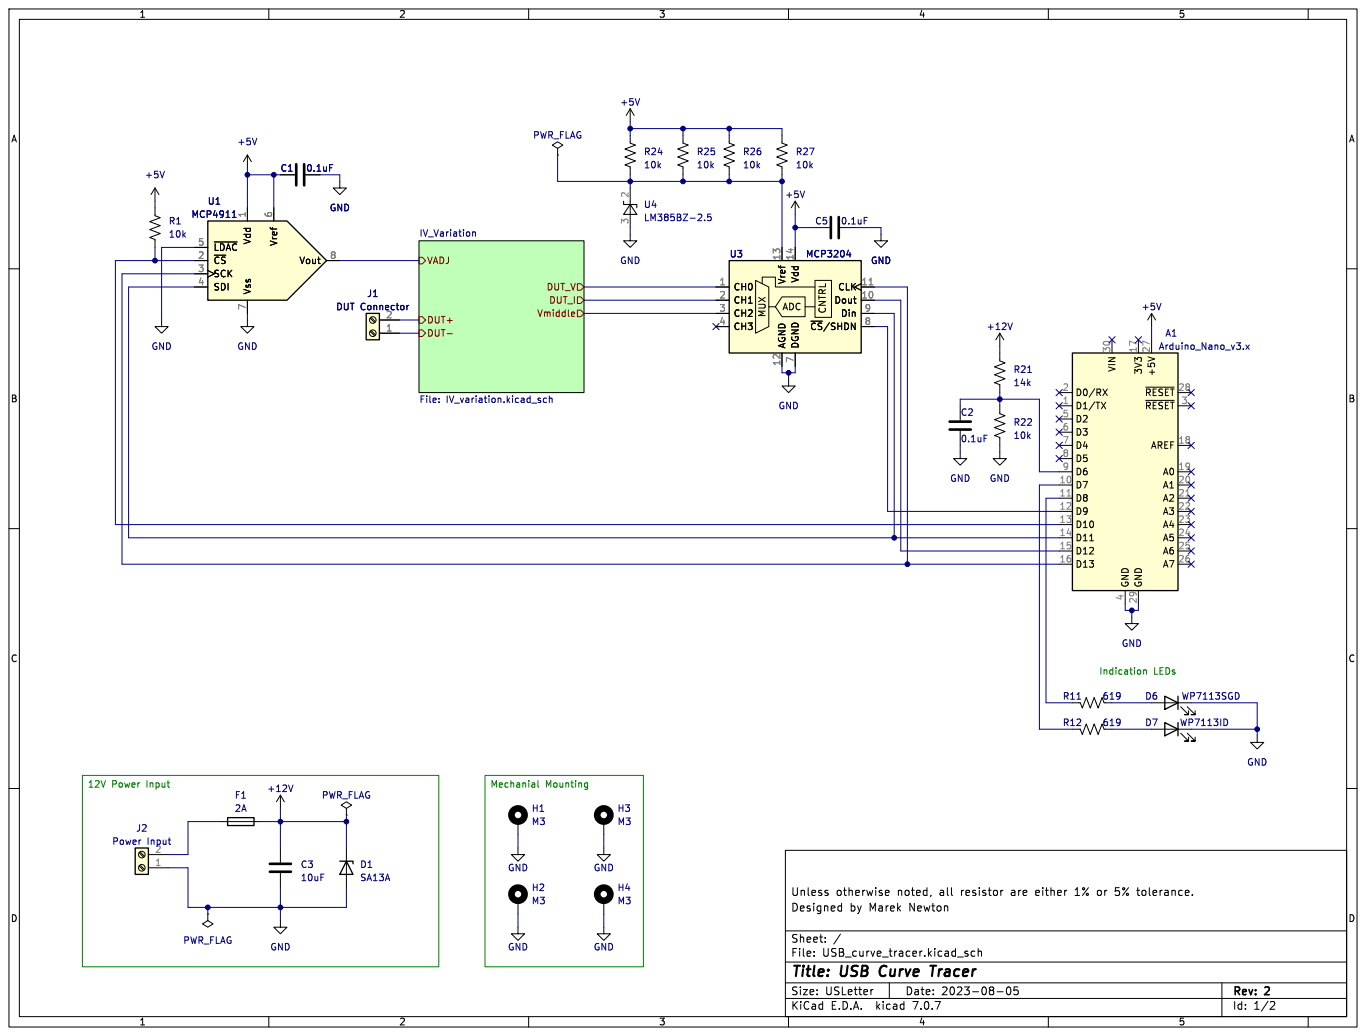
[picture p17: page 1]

1 ~{CS} 2 SCK 3 SDI 4 ~{LDAC} 5 Vref 6 Vss 7 Vout 8 U1 MCP4911 C1 0.1uF R21

1 ~{CS} 2 SCK 3 SDI 4 ~{LDAC} 5 Vref 6 Vss 7 Vout 8GND

4 D2 5 D3 6 D4 7 D5 8 D6 9 A1 Arduino_Nano_v3.x GND MUX ADC CNTRLCH0 1 Dout 10 CLK 11 AGND 12 Vref 13 Vdd 14 CH1 2 CH2 3 CH3 4 DGND

7 ~{CS}/SHDN 8 Din 9 U3 MCP3204 GND

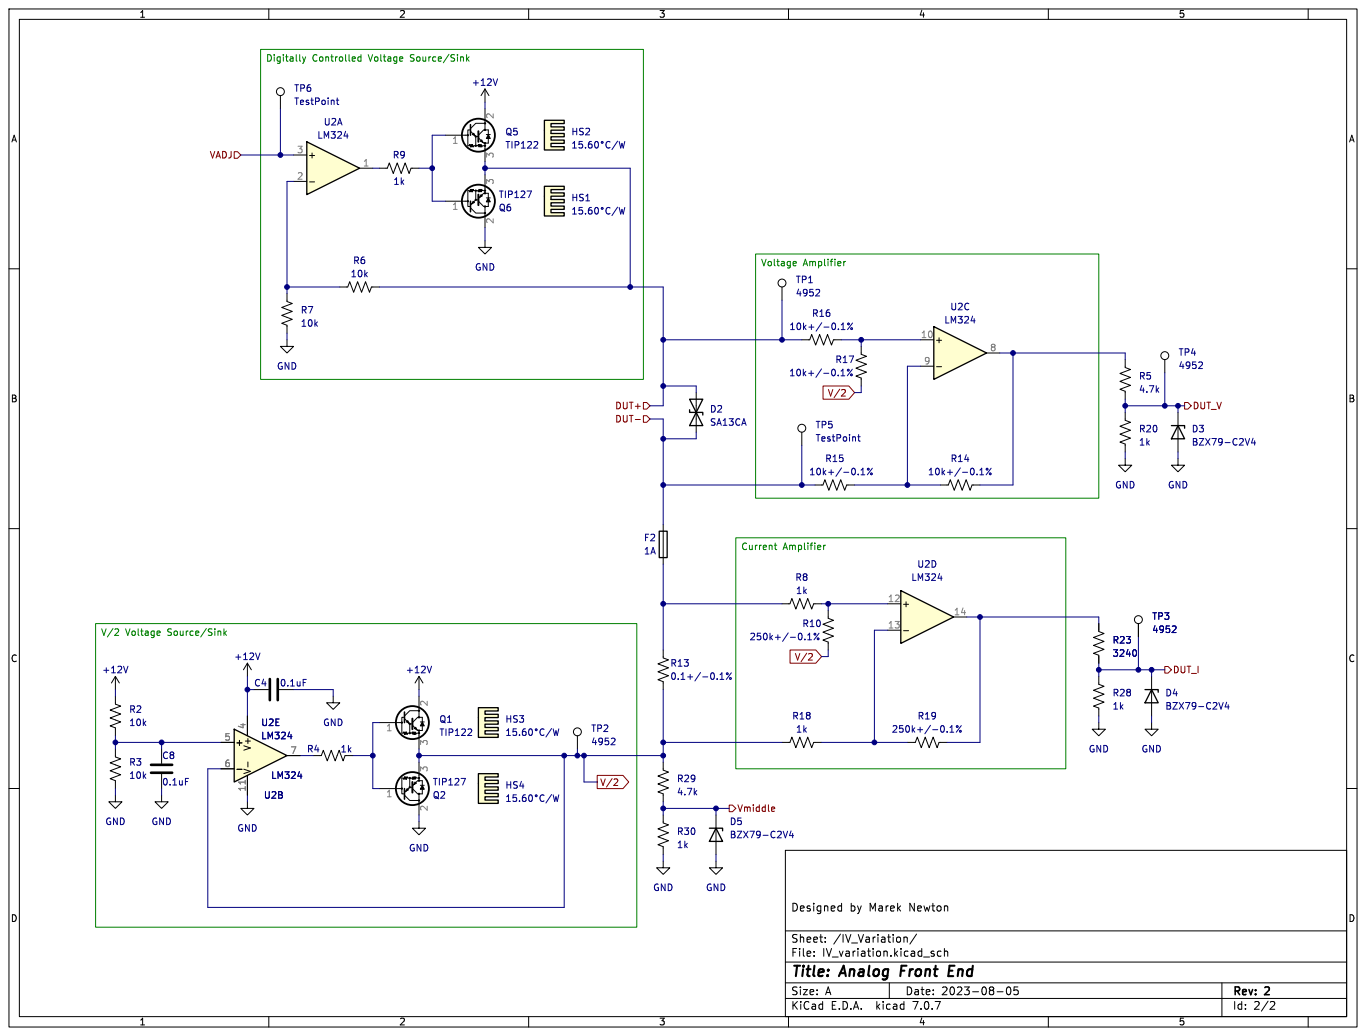
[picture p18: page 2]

Voltage Amplifier Current Amplifier V/2 Voltage Source/Sink

File: IV_variation.kicad_sch Sheet: /IV_Variation/
Id: 2/2 Title: Analog Front End

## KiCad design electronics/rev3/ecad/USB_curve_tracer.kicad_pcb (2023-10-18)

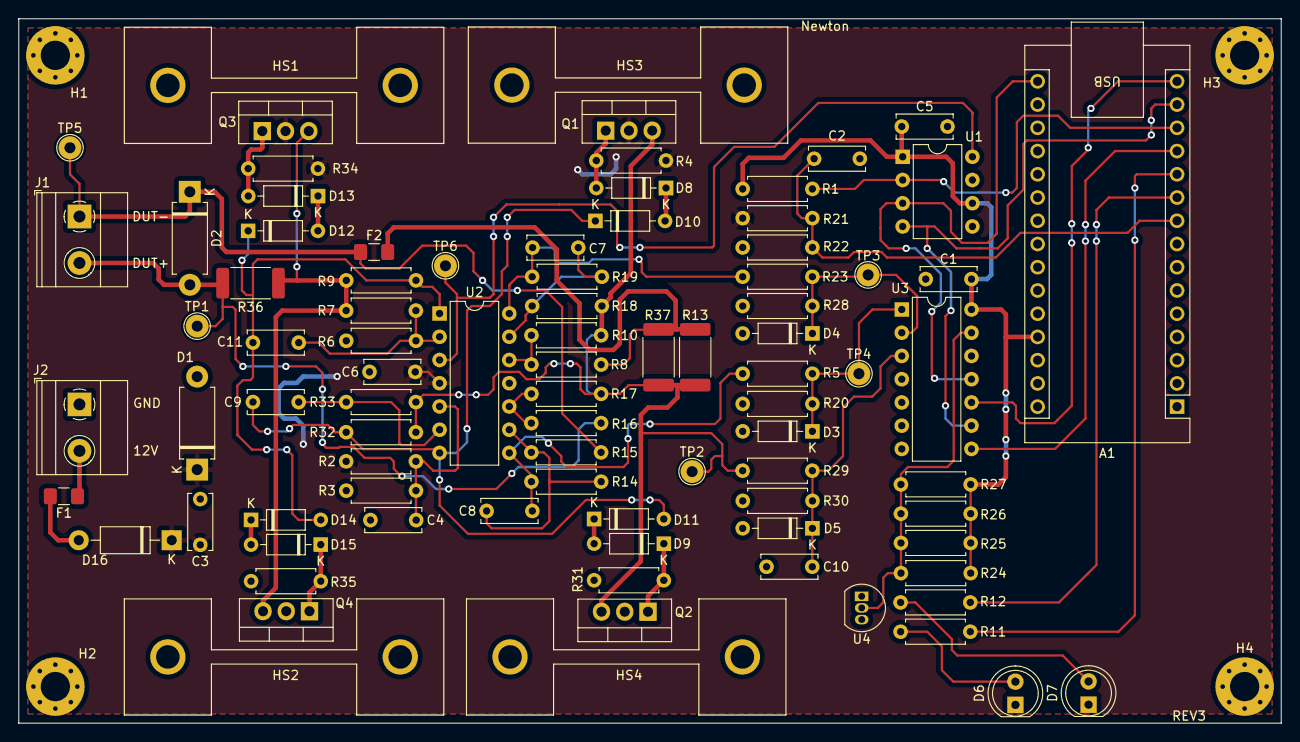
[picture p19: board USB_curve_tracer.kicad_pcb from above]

Board: 2 copper layers, 138.0 x 77.0 mm, 91 parts (0 on the bottom side), 44 nets.

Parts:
A1: Arduino_Nano_v3.x; Arduino_Nano
C1, C2, C4, C5, C6, C10: 0.1uF; C_Disc_D6.0mm_W2.5mm_P5.00mm
C3: 10uF; C_Disc_D6.0mm_W2.5mm_P5.00mm
C7, C8: 10nF; C_Disc_D6.0mm_W2.5mm_P5.00mm
C9, C11: 100pF; C_Disc_D6.0mm_W2.5mm_P5.00mm
D1: SA13A; D_DO-15_P10.16mm_Horizontal
D2: SA13CA; D_DO-15_P10.16mm_Horizontal
D3, D4, D5: BZX79-C2V4; D_DO-35_SOD27_P7.62mm_Horizontal
D6: WP7113SGD; LED_D5.0mm
D7: WP7113ID; LED_D5.0mm
D8, D9, D10, D11, D12, D13, D14, D15: 1N4148; D_DO-35_SOD27_P7.62mm_Horizontal
D16: 1N5817; D_DO-41_SOD81_P10.16mm_Horizontal
F1: 3A; Fuse_1206_3216Metric_Pad1.42x1.75mm_HandSolder
F2: 1A; Fuse_1206_3216Metric_Pad1.42x1.75mm_HandSolder
H1, H2, H3, H4: M3; MountingHole_3.2mm_M3_Pad_Via
HS1, HS2, HS3, HS4: 13.40°C/W; HSINK_531002B02500G
J1: DUT Connector; TerminalBlock_Phoenix_MKDS-1,5-2-5.08_1x02_P5.08mm_Horizont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
J2: Power Input; TerminalBlock_Phoenix_MKDS-1,5-2-5.08_1x02_P5.08mm_Horizont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
Q1, Q3: TIP122; TO-220-3_Vertical
Q2, Q4: TIP127; TO-220-3_Vertical
R1, R2, R3, R6, R7, R22, R24, R25, R26, R27, R33: 10k; R_Axial_DIN0207_L6.3mm_D2.5mm_P7.62mm_Horizontal
R4, R31, R34, R35: 4.7k; R_Axial_DIN0207_L6.3mm_D2.5mm_P7.62mm_Horizontal
R5, R23, R29: 3.83k+/-0.1%; R_Axial_DIN0207_L6.3mm_D2.5mm_P7.62mm_Horizontal
R8, R18, R20, R28: 1k+/-0.1%; R_Axial_DIN0207_L6.3mm_D2.5mm_P7.62mm_Horizontal
R9, R30, R32: 1k; R_Axial_DIN0207_L6.3mm_D2.5mm_P7.62mm_Horizontal
R10, R19: 11.8k+/-0.1%; R_Axial_DIN0207_L6.3mm_D2.5mm_P7.62mm_Horizontal
R11, R12: 619; R_Axial_DIN0207_L6.3mm_D2.5mm_P7.62mm_Horizontal
R13, R37: 1+/-1%; R_2512_6332Metric_Pad1.40x3.35mm_HandSolder
R14, R15, R16, R17: 10k+/-0.1%; R_Axial_DIN0207_L6.3mm_D2.5mm_P7.62mm_Horizontal
R21: 14k; R_Axial_DIN0207_L6.3mm_D2.5mm_P7.62mm_Horizontal
R36: 1.5; R_2512_6332Metric_Pad1.40x3.35mm_HandSolder
TP1, TP2, TP3, TP4, TP5, TP6: 4952; TestPoint_THTPad_D2.5mm_Drill1.2mm
U1: MCP4911; DIP-8_W7.62mm
U2: LMC6484A; DIP-14_W7.62mm
U3: MCP3204; DIP-14_W7.62mm
U4: LM385BZ-2.5; TO-92_Inline

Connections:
+5V: A1.27 (+5V), C1.1, C5.1, R1.1, R24.1, R25.1, R26.1, R27.1, U1.1 (Vdd), U1.6 (Vref), U3.14 (Vdd)
+12V: C3.1, C6.1, D1.1 (K), D16.1 (K), Q1.2 (C), Q3.2 (C), R2.1, R4.1, R21.1, R34.1, U2.4 (V+)
/IV_Variation/DUT_I: D4.1 (K), R23.2, R28.1, TP3.1, U3.2 (CH1)
/IV_Variation/DUT_V: D3.1 (K), R5.2, R20.1, TP4.1, U3.1 (CH0)
/IV_Variation/Sweep Voltage Buffer/Sweep_Amplified: Q3.3 (E), Q4.3 (E), R7.2, R9.2, R36.1
/IV_Variation/Sweep_Input: TP6.1, U1.8 (Vout), U2.3 (+)
/IV_Variation/Vmiddle: C10.1, D5.1 (K), R29.2, R30.1, U3.3 (CH2)
GND: A1.4 (GND), A1.29 (GND), C1.2, C2.2, C3.2, C4.2, C5.2, C6.2, C10.2, D1.2 (A), D3.2 (A), D4.2 (A), D5.2 (A), D6.1 (K), D7.1 (K), H1.1, H2.1, H3.1, H4.1, J2.1, Q2.2 (C), Q4.2 (C), R3.2, R6.2, R20.2, R22.2, R28.2, R30.2, R31.2, R35.2, U1.5 (~LDAC), U1.7 (Vss), U2.11 (V-), U3.7 (DGND), U3.12 (AGND), U4.3 (A)
unnamed: A1.9 (D6), C2.1, R21.2, R22.1
unnamed: A1.10 (D7), R12.2
unnamed: A1.11 (D8), R11.2
unnamed: A1.12 (D9), U3.8 (~CS/SHDN)
unnamed: A1.13 (D10), R1.2, U1.2 (~CS)
unnamed: A1.14 (D11), U1.4 (SDI), U3.9 (Din)
unnamed: A1.15 (D12), U3.10 (Dout)
unnamed: A1.16 (D13), U1.3 (SCK), U3.11 (CLK)
unnamed: C7.2, R19.2, R23.1, U2.14
unnamed: C8.2, R5.1, R14.2, U2.8
unnamed: D2.1 (A1), F2.1, J1.1, R15.1, TP5.1
unnamed: D2.2 (A2), J1.2, R16.1, R36.2, TP1.1
unnamed: D6.2 (A), R11.1
unnamed: D7.2 (A), R12.1
unnamed: D8.2 (A), Q1.1 (B), R4.2
unnamed: D9.1 (K), Q2.1 (B), R31.1
unnamed: D8.1 (K), D10.2 (A)
unnamed: C9.2, D10.1 (K), D11.2 (A), R32.1, U2.7
unnamed: D9.2 (A), D11.1 (K)
unnamed: D12.2 (A), D13.1 (K)
unnamed: C11.1, D12.1 (K), D14.2 (A), R9.1, U2.1
unnamed: D13.2 (A), Q3.1 (B), R34.2
unnamed: D14.1 (K), D15.2 (A)
unnamed: D15.1 (K), Q4.1 (B), R35.1
unnamed: D16.2 (A), F1.2
unnamed: F2.2, R8.1, R13.1, R37.1
unnamed: F1.1, J2.2
unnamed: C11.2, R6.1, R7.1, U2.2 (-)
unnamed: C4.1, R2.2, R3.1, U2.5 (+)
unnamed: C9.1, R33.1, U2.6 (-)
unnamed: R16.2, R17.1, U2.10 (+)
unnamed: C8.1, R14.1, R15.2, U2.9 (-)
unnamed: R8.2, R10.1, U2.12 (+)
unnamed: C7.1, R18.2, R19.1, U2.13 (-)
unnamed: R24.2, R25.2, R26.2, R27.2, U3.13 (Vref), U4.2 (K)
V/2: Q1.3 (E), Q2.3 (E), R10.2, R13.2, R17.2, R18.1, R29.1, R32.2, R33.2, R37.2, TP2.1

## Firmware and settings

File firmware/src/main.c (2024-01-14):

//
// FILENAME: main.c
//
// description: This is main file for the USB curve tracer program. This file contains
// most of the control, zeroing, and sweeping of the device. 
//
// Written by Marek Newton
//

#include <avr/io.h>
#include <stdint.h>

#include "main.h"

#include "UART.h"
#include "spi.h"
#include "MCP3204.h"
#include "MCP4911.h"

static uint16_t DAC_voltage_setting;
static Mode mode;
static uint8_t sweeping;
static uint8_t user_programmed_current_limit_used;
static uint16_t user_programmed_current_limit;

int main(void)
{
    DAC_voltage_setting = 0;
    sweeping = 0;
    user_programmed_current_limit_used = 0;

    setup_UART();
    setup_IO();
    setup_SPI();

    mode = BIDIRECTIONAL;
    zero_device_voltage();

    while(1)
    {
        device_operation();
        if(!sweeping)
        {
            zero_device_voltage();
            turn_on_green_LED();
        }
    }

    // The program should never return. 
    return 0;
}

void device_operation(void)
{
    zero_device_voltage();
    turn_off_red_LED();
    turn_on_green_LED();
    uint8_t command = UART_receive_character();

    if(!external_voltage_supply_detected())
    {
        power_disconnected(command);
    }
    else
    {
        switch(command)
        {
            case SWEEP_COMMAND_CHARACTER:
                turn_off_green_LED();
                turn_on_red_LED();
                sweep_device();
                turn_off_red_LED();
                turn_on_green_LED();
                break;
            case UNIDIRECTIONAL_COMMAND_CHARACTER:
                mode = UNIDIRECTIONAL;
                break;
            case BIDIRECTIONAL_COMMAND_CHARACTER:
                mode = BIDIRECTIONAL;
                break;
            case CURRENT_LIMIT_COMMAND_CHARACTER:
                user_programmed_current_limit = receive_current_code();
                user_programmed_current_limit_used = 1;
                UART_transmit_uint16_t(user_programmed_current_limit);
                UART_transmit_string(CURRENT_LIMIT_SET);
                break;
            case MAX_CURRENT_LIMIT_COMMAND_CHARACTER:
                user_programmed_current_limit_used = 0;
                break;
            default:
                break;
        }
    }
}

void power_disconnected(uint8_t command)
{
    turn_on_red_LED();
    turn_off_green_LED();

    if(command == SWEEP_COMMAND_CHARACTER || 
    command == UNIDIRECTIONAL_COMMAND_CHARACTER || 
    command == BIDIRECTIONAL_COMMAND_CHARACTER)
    {
        print_starting_command();
        print_power_disconnected();
        print_ending_command();
    }
}

void turn_on_green_LED(void)
{
    PORTB |= (1 << PORTB0);
}

void turn_off_green_LED(void)
{
    PORTB &= ~(1 << PORTB0);
}   

void turn_on_red_LED(void)
{
    PORTD |= (1 << PORTD7);
}

void turn_off_red_LED(void)
{
    PORTD &= ~(1 << PORTD7);
}

void setup_IO(void)
{
    // Set MOSI and SCK to output for SPI.
    DDRB |= (1 << DDB3);
    DDRB |= (1 << DDB5);
    // Set both CS pins to output. 
    DDRB |= (1 << DDB1);
    DDRB |= (1 << DDB2);
    // Set the LED pins to outputs. 
    DDRB |= (1 << DDB0);
    DDRD |= (1 << DDD7);
    // Set the supply voltage detect to input.
    DDRD &= ~(1 << DDD6);
}

uint8_t external_voltage_supply_detected(void)
{
    return (PIND & (1 << PIND6)) != 0;
}

void zero_device_voltage(void)
{
    uint16_t reference_voltage = get_ADC_reading(SINGLE_ENDED, REFERENCE_ADC_CHANNEL);

    while(1)
    {
        uint16_t voltage_reading = get_ADC_reading(SINGLE_ENDED, VOLTAGE_ADC_CHANNEL);

        if(voltage_reading > reference_voltage && DAC_voltage_setting > 0)
        {
            DAC_voltage_setting--;
        }
        else if(voltage_reading < reference_voltage && DAC_voltage_setting <= DAC_RESOLUTION)
        {
            DAC_voltage_setting++;
        }

        set_DAC(DAC_voltage_setting, GAIN_1X, BUFFERED);

        uint8_t above_range = voltage_reading > reference_voltage + ZERO_DEVICE_MARGIN;
        uint8_t below_range = voltage_reading < reference_voltage - ZERO_DEVICE_MARGIN;

        if(!above_range && !below_range)
        {
            break;
        }
    }
}

uint16_t receive_current_code(void)
{
    // most significant byte first
    uint8_t bytes[CURRENT_CODE_BYTE_COUNT];
    uint8_t byte_count = 0;

    while(1)
    {
        uint8_t byte = (uint8_t)UART_receive_character();
        if(byte != 0)
        {
            bytes[byte_count] = byte;
            byte_count++;
            if(byte_count == CURRENT_CODE_BYTE_COUNT)
            {
                break;
            }
        }
    }

    return bytes[0] << BYTE_SIZE | bytes[1];
}

IV_Sample sample_IV(void)
{
    IV_Sample iv_sample;
    iv_sample.voltage_code = get_ADC_reading(SINGLE_ENDED, VOLTAGE_ADC_CHANNEL);
    iv_sample.current_code = get_ADC_reading(SINGLE_ENDED, CURRENT_ADC_CHANNEL);
    return iv_sample;
}

uint8_t over_current(IV_Sample sample)
{
    if(user_programmed_current_limit_used && user_programmed_current_limit > 900)
    {
        return sample.current_code > user_programmed_current_limit;
    }
    else
    {
        return sample.current_code > MAX_POSITIVE_CURRENT_CODE || sample.current_code < MAX_NEGATIVE_CURRENT_CODE;
    }
}

void print_starting_command(void)
{
    UART_transmit_string(START_COMMAND);
    UART_transmit_string(NEW_LINE);
}

void print_ending_command(void)
{
    UART_transmit_string(END_COMMAND);
    UART_transmit_string(NEW_LINE);
}

void print_power_disconnected(void)
{
    UART_transmit_string(POWER_DISCONNECTED);
    UART_transmit_string(NEW_LINE);
}

void print_sample(IV_Sample sample)
{
    UART_transmit_uint16_t(sample.current_code);
    UART_transmit_string(DELIMINATOR);
    UART_transmit_uint16_t(sample.voltage_code);
    UART_transmit_string(NEW_LINE_AND_CARRIAGE_RETURN);
}

void sweep_device(void)
{
    print_starting_command();
    zero_device_voltage();

    while(DAC_voltage_setting <= MAXIMUM_DAC_CODE)
    {
        DAC_voltage_setting++;
        set_DAC(DAC_voltage_setting, GAIN_1X, BUFFERED);
        IV_Sample sample;
        sample = sample_IV();
        print_sample(sample);

        if(over_current(sample))
        {
            break;
        }
    }

    zero_device_voltage();

    if(mode == BIDIRECTIONAL)
    {
        while(DAC_voltage_setting > MINIMUM_DAC_CODE)
        {
            DAC_voltage_setting--;
            set_DAC(DAC_voltage_setting, GAIN_1X, BUFFERED);
            IV_Sample sample;
            sample = sample_IV();
            print_sample(sample);

            if(over_current(sample))
            {
                break;
            }
        }

        zero_device_voltage();
    }

    print_ending_command();
}

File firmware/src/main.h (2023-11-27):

#ifndef MAIN_H
#define MAIN_H

#include <stdint.h>

#define HARDWARE_REVISION 3

#define AVERAGING_SAMPLE_COUNT 10

#define VOLTAGE_ADC_CHANNEL 0
#define CURRENT_ADC_CHANNEL 1
#define REFERENCE_ADC_CHANNEL 2
#define CURRENT_CODE_BYTE_COUNT 2

#define MAXIMUM_ADC_READING 4095

#if HARDWARE_REVISION == 2
   
#define MAX_POSITIVE_CURRENT_CODE 4090
#define MAX_NEGATIVE_CURRENT_CODE 500

#elif HARDWARE_REVISION == 3

// Maximum current is +/- 0.75A
// 5.841 Measured Reference Voltage
// LSB: 610.4uV

#define MAX_POSITIVE_CURRENT_CODE 3350
#define MAX_NEGATIVE_CURRENT_CODE 462

#endif

#define ZERO_DEVICE_MARGIN 3

#define MAXIMUM_DAC_CODE 1023
#define MINIMUM_DAC_CODE 0

// PC Communication Protocol.
#define DELIMINATOR ","

#define SWEEP_COMMAND_CHARACTER 's'

#define UNIDIRECTIONAL_COMMAND_CHARACTER 'u'
#define BIDIRECTIONAL_COMMAND_CHARACTER 'b'

#define CURRENT_LIMIT_COMMAND_CHARACTER 'c'
#define MAX_CURRENT_LIMIT_COMMAND_CHARACTER 'm'

#define START_COMMAND "START"
#define END_COMMAND "END"
#define POWER_DISCONNECTED "P"

#define CURRENT_LIMIT_SET "L"

typedef struct 
{
    uint16_t voltage_code;
    uint16_t current_code;
} IV_Sample;

typedef enum
{
    UNIDIRECTIONAL,
    BIDIRECTIONAL
} Mode;

void device_operation(void);

void setup_IO(void);
void DAC_CS_toggle(void);
void ADC_CS_toggle(void);
uint32_t average_ADC_reading(uint8_t channel);
void zero_device_voltage(void);
void sweep_device(void);
uint8_t external_voltage_supply_detected(void);
void print_power_disconnected(void);
void power_disconnected(uint8_t command);
uint16_t receive_current_code(void);

void print_starting_command(void);
void print_ending_command(void);

// LED Control
void turn_on_green_LED(void);
void turn_off_green_LED(void);
void turn_on_red_LED(void);
void turn_off_red_LED(void);

#endif

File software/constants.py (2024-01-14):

DAC_BIT_RESOLUTION = 10
ADC_BIT_RESOLUTION = 12

NEWLINE = '\n'
COMMA = ','

BAUDRATE = 9600
SERIAL_PORT = '/dev/ttyUSB0'

DATA_START_COMMAND = 'START'
DATA_END_COMMAND = 'END'

TRANSMIT_STRING_GARBAGE = '\x00'

SWEEP_PROCESSOR_COMMAND = b's'
UNIDIRECTIONAL_PROCESSOR_COMMAND = b'u'
BIDIRECTIONAL_PROCESSOR_COMMAND = b'b'

POWER_DISCONNECTED = 'P'
CURRENT_LIMIT_PROCESSOR_COMMAND = b'c'
MAX_CURRENT_LIMIT_PROCESSOR_COMMAND = b'm'
CURRENT_LIMIT_ACK = 'L'

DATA_RECEIVE_DELAY = 0.1
SECOND_DELAY = 1
TITLE_COMMAND_LIST_LENGTH = 2

# Plotting Settings
GRAPH_DECIMAL_DIGIT_COUNT = 2
SCATTER_PLOT_DOT_SIZE = 4
BASE_CURRENT_LABEL = 'Base Current'
BASE_EMITTER_VOLTAGE_LABEL = 'Base Emitter Voltage'
GATE_SOURCE_VOLTAGE_LABEL = 'Gate Source Voltage'
PREFIX_STRINGS = ['','m', 'u']
UNIT_STRINGS = ['V', 'A']

DECODING_SCHEME = 'utf8'

FILE_WRITE = 'wt'

CSV_EXTENSION = '.csv'

IV_TRACE_TITLE = 'IV Trace'

NO_DATA_ERROR_COUNT = 10
ACK_READ_ATTEMPTS = 10
MAXIMUM_USER_CURRENT_LIMIT = 0.7

# Messages
COMPONENT_CONNECTION_MESSAGE = 'Safe to connect component to curve tracer.'
OPENING_ERROR = 'Serial port could not be opened.'
NO_DATA_ERROR = 'No data received.'
DATA_READ_ERROR = 'Data could not be read'
COMMAND_PROMPT = 'Enter a command: '
TITLE_PROMPT = 'Enter a title:'
INVALID_COMMAND_ERROR = 'Invalid command'
STORED_SWEEPS_ERROR = 'No Stored Sweeps'
POWER_DISCONNECTED_ERROR = '12V Power is disconnected from the curve tracer.'
CURRENT_LIMIT_UNIDIRECTIONAL = 'Changing to Unidirectional mode.'
INVALID_CURRENT_LIMIT = 'Invalid Current limit Entered'
CURRENT_LIMIT_PROMPT = 'Enter a new current limit:'

# User Commands
SWEEP_USER_COMMAND = 'sweep'
CSV_USER_COMMAND = 'csv'
EXIT_USER_COMMAND = 'exit'
UNIDIRECTIONAL_USER_COMMAND = 'unidirectional'
BIDIRECTIONAL_USER_COMMAND = 'bidirectional'
REV2_USER_COMMAND = 'rev2'
REV1_USER_COMMAND = 'rev1'
CURRENT_LIMIT_COMMAND = 'current_limit'
MAX_CURRENT_LIMIT_COMMAND = 'max_current_limit'

# Plots
THEORETICAL_TRACE_COLOR = 'red'
MEASURED_LABEL = 'measured'
THEORETICAL_LABEL = 'theoretical'

VOLTAGE_AXIS_LABEL = 'Voltage (V)'
CURRENT_AXIS_LABEL = 'Current (A)'

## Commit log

2023-08-03 solid front end
    [IV_variation.kicad_sch, USB_curve_tracer.kicad_sch]
2023-08-04 schematic work
    [IV_variation.kicad_sch, USB_curve_tracer.kicad_sch]
2023-08-08 restructuring and layout
    [1N4148_manual_curve_trace.ods, 1N4148_manual_curve_trace.xlsx, BOM.csv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]
2023-08-15 removed ignored files
    [BOM.csv, IV_variation.kicad_sch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]
2023-08-27 created firmware baseline
    [BOM.csv]
2023-08-27 starting firmware
    [Enclosure_Body.scad]
2023-08-28 DAC output voltage
2023-08-28 DAC and ADC
2023-08-29 Working ADC
2023-09-11 Linear Output
    [BOM.csv, IV_variation.kicad_sch, USB_curve_tracer.kicad_pcb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]
2023-09-13 proper ADC implementation
    [1N4148_manual_curve_trace.ods, data.csv, data220.csv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]
2023-09-13 DAC driver
2023-09-15 proper ramp and ADC
    [data470.csv, data680.csv, data_open.csv]
2023-09-16 zener plot
    [data470.csv, data_zener.csv]
2023-09-16 start of PC interface
    [data680.csv, data_open.csv]
2023-09-23 preliminary box
    [Curve_Tracer_BOM.csv, Enclosure_Body.scad, box-Body.stl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]
2023-09-24 resistor testing
    [data220.csv, data33.csv, data330.csv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]
2023-09-25 added device picture
2023-09-25 removed mechanical
    [box-Body.stl, box.FCStd]
2023-09-27 REV3 start
    [IV_variation.kicad_sch, PCB_Project.PrjPcb, Sheet1.SchDoc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]
2023-10-01 REV3 schematic
    [IV_variation.kicad_sch, USB_curve_tracer.kicad_sch, sweep_voltage_buffer.kicad_sch]
2023-10-06 Layout work
    [IV_variation.kicad_sch, USB_curve_tracer.kicad_pcb, USB_curve_tracer.kicad_sch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]
2023-10-18 start direction modes
    [531002B02500G.step, IV_variation.kicad_sch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]
2023-10-21 power disconnected
2023-10-22 value changes
    [USB_curve_tracer.kicad_sch, USB_curve_tracer_rev3_BOM.csv]
2023-11-02 added tolerance
    [IV_variation.kicad_sch]
2023-11-03 some traces on rev3
2023-11-04 some more rev3 traces and some problems
    [bad_diode_trace.csv]
2023-11-05 REV3 testing
    [data220.csv, data33.csv, data33.csv.csv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]
2023-11-05 start of current limiting
2023-11-05 removed zener diodes
    [IV_variation.kicad_sch]
2023-11-08 TIP122G test
    [#1.csv, #2.csv, #3.csv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]
2023-11-10 changed crossover resistor to 330
    [220.csv, 33.csv, 330.csv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]
2023-11-10 LMC6484 REV3 test
    [data0.csv, data1.csv, data2.csv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]
2023-11-12 debug and misc
    [half_supply_buffer.kicad_sch, sweep_voltage_buffer.kicad_sch]
2023-11-18 more current limit work
2023-11-21 mechanical stuff
    [BOM.csv, M3_stand_off.scad, M3_stand_off.stl]
2023-11-28 working current limit
2023-11-28 new examples
    [#1.csv, #2.csv, #3.csv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]
2023-12-10 comparison test
    [1N4001_CT.csv, 1N4001_manual.csv, 1N4148_CT.csv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]
2023-12-13 rev3 resistor test final
    [220.csv, 33.csv, 330.csv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]
2023-12-15 attempy at scope comparison
    [1N4001_CT.csv, 1N4148_CT.csv]
2023-12-17 scope comparison
    [1N4001_AD3.csv, 1N4148_AD3.csv]
2023-12-23 Revert "scope comparison"
    This reverts commit d555587def78571ea5c9663f421cd88214450a50.
    [1N4001_AD3.csv, 1N4148_AD3.csv]
2023-12-24 mosfet sweep
    [#1.csv, #2.csv, #3.csv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]
2024-01-14 started step average
    [#1.csv, #2.csv, #3.csv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]
2024-01-14 Revert "started step average"
    This reverts commit faad6ccbaa3a507dd0bd96a70cac3c427b262546.
    [#1.csv, #2.csv, #3.csv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]
2024-03-11 added schematic to readme
